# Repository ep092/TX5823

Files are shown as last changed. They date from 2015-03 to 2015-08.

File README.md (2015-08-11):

# TX5823
FPV Sender mit Kanalwahl und konfiguration über SPI. Integriertes OSD mit MAX7456 und Spannungswandlern für 5V, 3,3V und Vorbereitung für 12V, über einen Eingangsspannungsbereich von 8V bis 25.2V.
Das OSD ist kompatibel zu minimosd und wird mit dessen Firmware betrieben und mit der entsprechenden Software konfiguriert.
Die Kanalwahl folgt über einen freien Empfängerkanal.
Zusätzlich ist ein Infrarotauslöser für Canonkameras vorgesehen.

-------------------
Status:
- schaltplan fertig
- layout fertig
- platine bestellt
- Bauteile bestellt
- platine bestückt
- Tests erfolgreich

-------------------
Steckerbelegung 3-reihige Pinleiste(Orientierung Pinleiste nach links, oben 1):

untere Reihe, mittlere Reihe, obere Reihe

1. GND, NC, Video in
2. GND, NC, Sound in
3. GND, NC, PWM in
4. Infrator LED -, NC, Infrarot LED +
5. GND, 5V out, NC
6. GND. 5V out, NC
7. GND, 12V out (optional), NC
8. GND, 12V out (optional), NC

-------------------

Steckerbelegung mavlink Stecker

1. DTR (für Reset über USB)
2. TX (Atmega Daten Senden)
3. RX (Atmega Daten Empfangen)
4. 5/3,3V
5. GND

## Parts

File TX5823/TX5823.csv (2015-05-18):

Reference | Value | Footprint | Datasheet | Teilenummer | Bestellnummer | Anzahl lagernd
U2 | TPS54531 | toni:SO8_EP |  |  |  | 3 | d
U6 | TX5823 | toni:TX5823 |  |  |  | 0
U7 | MAX7456_DS | toni:TSSOP-28_4.4x9.7mm_Pitch0.65mm_EP |  |  |  | 4
IC1 | ATMEGA328P-A | Housings_QFP:TQFP-32_7x7mm_Pitch0.8mm |  |  |  | 20
IC2 | ATTINY13A-SS | SMD_Packages:SOIC-8-N |  |  |  | 20
R24 | 10k | Resistors_SMD:R_0603 |  |  |  | 0 | d
U3 | TPS7A7200RGT | toni:QFN-16-1EP_3x3mm_Pitch0.5mm |  |  |  | 3
R23 | 10 | Resistors_SMD:R_0805 |  |  |  | x
Q3 | MOSFET_N | toni:SOT23_GDS |  |  |  | x
R25 | 100 | Resistors_SMD:R_1206 |  |  |  | x
C29 | 100nF | Capacitors_SMD:C_0402 |  |  |  | x
C31 | 100nF | Capacitors_SMD:C_0402 |  |  |  | x
C19 | 1uF | Capacitors_SMD:C_0603 |  |  |  | x
C21 | 100nF | Capacitors_SMD:C_0402 |  |  |  | x
C32 | 1uF | Capacitors_SMD:C_0603 |  |  |  | x
C26 | 1uF | Capacitors_SMD:C_0603 |  |  |  | x
C27 | 10uF | Capacitors_SMD:C_1206 |  |  |  | x
C22 | 100nF | Capacitors_SMD:C_0402 |  |  |  | x
R17 | open | Resistors_SMD:R_0402 |  |  |  | x
R19 | open | Resistors_SMD:R_0402 |  |  |  | x
R20 | open | Resistors_SMD:R_0402 |  |  |  | x
C23 | 100nF | Capacitors_SMD:C_0402 |  |  |  | x
SW1 | SW_PUSH | toni:EVQP7A |  |  |  | 0 | d
R13 | 10k | Resistors_SMD:R_0603 |  |  |  | 0 | d
C20 | 100nF | Capacitors_SMD:C_0402 |  |  |  | x
Y1 | 16MHz | toni:CerOsc_3,2x1,3 |  |  |  | 0 | r
R21 | open | Resistors_SMD:R_0402 |  |  |  | x
R22 | 330 | Resistors_SMD:R_0805 |  |  |  | 0 | d
D6 | LED | LEDs:LED-0603 |  |  |  | x
C35 | 47uF | Capacitors_Tantalum_SMD:TantalC_SizeB_EIA-3528_Reflow |  |  |  | 0 | d
C36 | 47uF | Capacitors_Tantalum_SMD:TantalC_SizeB_EIA-3528_Reflow |  |  |  | 0 | d
R29 | 75 | Capacitors_SMD:C_0805 |  |  |  | 0 | d
C33 | 100nF | Capacitors_SMD:C_0402 |  |  |  | x
C34 | 1uF | Capacitors_SMD:C_0603 |  |  |  | x
C37 | 100nF/NP0 | Capacitors_SMD:C_1206 |  | C3216C0G1H104J160AA |  | 0
R30 | 75 | Capacitors_SMD:C_0805 |  |  |  | r
C30 | 100nF | Capacitors_SMD:C_0402 |  |  |  | x
RP1 | 1k | Resistors_SMD:R_Array_Concave_4x0603 |  |  |  | 0 | r
P2 | ISP | toni:micro_match3x2 |  |  |  | 0 | r
X1 | 27MHz | toni:CRYSTAL_MT |  |  | NDK NX3225SA-27.000MHZ-STD-CSR-1 | 0 | d
C24 | 100nF | Capacitors_SMD:C_0402 |  |  |  | x
C25 | 100nF | Capacitors_SMD:C_0402 |  |  |  | x
C28 | 1uF | Capacitors_SMD:C_0603 |  |  |  | x
C14 | Cboot | Capacitors_SMD:C_0402 |  | C1005X5R1A104K |  | 0 | d
D1 | DIODE | toni:POWERDI5 |  | PDS760-13 |  | 0 | d
L1 | INDUCTOR | Choke_SMD:Choke_SMD_Wuerth-WE-PD-Typ-LS_Handsoldering |  |  |  | 4 | d
R10 | Rfbt | Resistors_SMD:R_0402 |  | CRCW040210K2FKED |  | 0 | d
R11 | Rfbb | Resistors_SMD:R_0402 |  | CRCW04021K96FKED |  | 0 | d
C16 | Cout | Capacitors_SMD:C_1210 |  | GRM32ER61E226KE15L |  | 0 | d
C11 | 10nF | Capacitors_SMD:C_0402 |  | GRM033R61A822KA01D |  | 0 | evtl
C8 | Ccomp | Capacitors_SMD:C_0805 |  | CC0805JRNPO9BN102 |  | 0 | d
R6 | Rcomp | Resistors_SMD:R_0402 |  | CRCW040252K3FKED |  | 0 | d
C5 | Ccomp2 | Capacitors_SMD:C_0805 |  | C0805C180K5GACTU |  | 0 | d
C3 | Cin | Capacitors_SMD:C_1210 |  | GRM32ER71H475KA88L |  | 0 | d
C17 | Cout | Capacitors_SMD:C_1210 |  | GRM32ER61E226KE15L |  | 0 | d
C1 | Cin | Capacitors_SMD:C_1210 |  | GRM32ER71H475KA88L |  | 0 | d
U4 | CONN_03X08 | toni:Conn_03x08 |  |  |  | 4
R12 | open | Resistors_SMD:R_0603 |  |  |  | x
R14 | open | Resistors_SMD:R_0603 |  |  |  | x
R15 | 0R | Resistors_SMD:R_0603 |  |  |  | x
R16 | open | Resistors_SMD:R_0603 |  |  |  | x
P3 | Mavlink | Connectors_Molex:Connector_Molex_PicoBlade_53261-0571 |  |  |  | 4
R27 | 1k | Resistors_SMD:R_0603 |  |  |  | r
R18 | 330R | Resistors_SMD:R_0805 |  |  |  | r
R28 | 1k | Resistors_SMD:R_0603 |  |  |  | r
P1 | Akku_in | Socket_Strips:Socket_Strip_Angled_1x02 |  |  |  | x
R31 | 330R | Capacitors_SMD:C_0805 |  |  |  | r
SMA_E1 | SMA_EDGE | toni:SMA_EDGE |  |  |  | 0 | phil
C2 | 220pF | Capacitors_SMD:C_0402 |  |  |  | 0 | d
U1 | TPS7A7200RGT | toni:QFN-16-1EP_3x3mm_Pitch0.5mm |  |  |  | r
C4 | 1uF | Capacitors_SMD:C_0603 |  |  |  | x
C6 | 100nF | Capacitors_SMD:C_0402 |  |  |  | x
C12 | 1uF | Capacitors_SMD:C_0603 |  |  |  | x
C7 | 100nF | Capacitors_SMD:C_0402 |  |  |  | x
C10 | 220pF | Capacitors_SMD:C_0402 |  |  |  | r
C13 | 10uF | Capacitors_SMD:C_1206 |  |  |  | x
Q1 | MOSFET_P | toni:SO8_WITH_EP |  | FDS4141 |  | x
R2 | R | Resistors_SMD:R_0603 |  |  |  | x
R1 | R | Resistors_SMD:R_0603 |  |  |  | x
R3 | R | Resistors_SMD:R_1206 |  | ersetzen durch ferrit s.u. |  | x
C9 | C | Capacitors_SMD:C_0603 |  |  |  | x
D2 | ZENER | Diodes_SMD:Diode-MiniMELF_Standard |  |  |  | x
R4 | 280k | Resistors_SMD:R_0603 |  | 0,10% |  | 0 | d
R5 | 30,9k | Resistors_SMD:R_0603 |  | 0,10% |  | 0 | d
P4 | CONN_01X01 | Pin_Headers:Pin_Header_Straight_1x01 |  |  |  | x
P5 | CONN_01X01 | Pin_Headers:Pin_Header_Straight_1x01 |  |  |  | x
P6 | CONN_01X01 | Pin_Headers:Pin_Header_Straight_1x01 |  |  |  | x
P7 | CONN_01X01 | Pin_Headers:Pin_Header_Straight_1x01 |  |  |  | x
U9 | TPS22963 | toni:DSBGS(6) |  |  |  | x
U5 | OPTO-TRANSISTOR4 | toni:SO-4 |  |  |  | 16
U8 | ADuM7241 ARZ | Housings_SOIC:SOIC-8_3.9x4.9mm_Pitch1.27mm |  |  |  | 3 | d
U10 | OPTO-TRANSISTOR4 | toni:SO-4 |  |  |  | r
R8 | 330R | Resistors_SMD:R_0603 |  |  |  | r
R7 | 10k | Resistors_SMD:R_0603 |  |  |  | 0 | d
C15 | 100nF | Capacitors_SMD:C_0402 |  |  |  | x
C18 | 100nF | Capacitors_SMD:C_0402 |  |  |  | x
D3 | P6SMB 27A SMD | Diodes_SMD:Diode-SMB_Standard |  |  |  | 0 | r
 | ferrit würth |  |  | 742792150 |  | 0 | d

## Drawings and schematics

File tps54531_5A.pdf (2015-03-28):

## WEBENCH ® Design Report

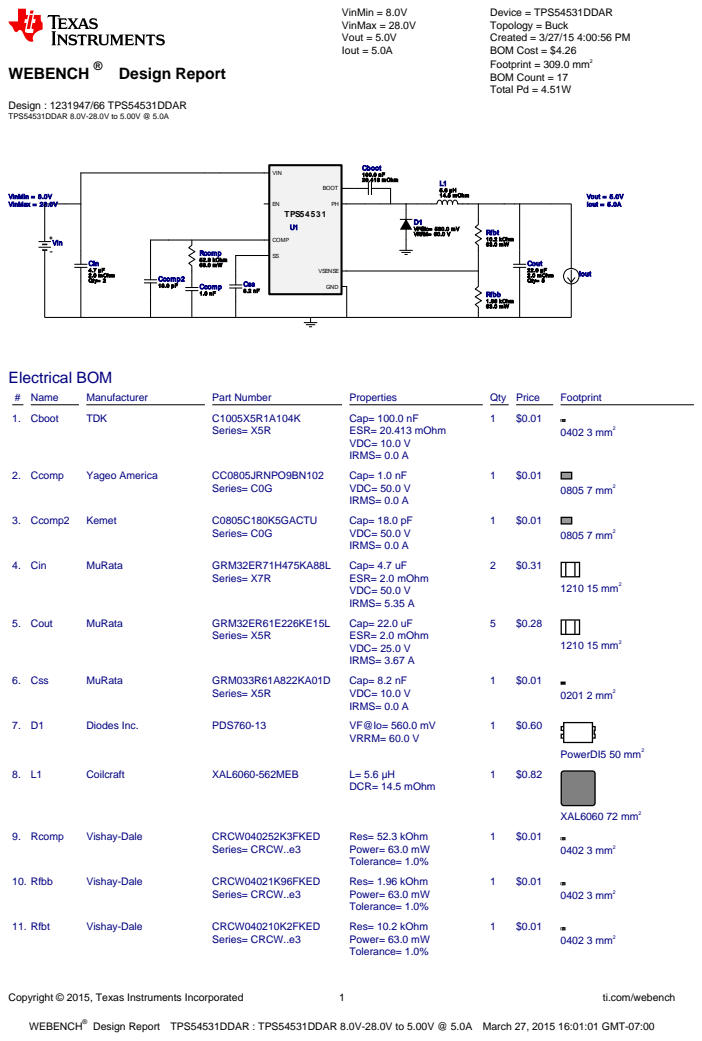
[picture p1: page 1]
Copyright © 2015, Texas Instruments Incorporated; ti.com/webench; WEBENCH®; Design : 1231947/66 TPS54531DDAR TPS54531DDAR 8.0V-28.0V to 5.00V @ 5.0A; VinMin = 8.0V VinMax = 28.0V Vout = 5.0V Iout = 5.0A; Device = TPS54531DDAR Topology = Buck Created = 3/27/15 4:00:56 PM BOM Cost = $4.26 Footprint = 309.0 mm² BOM Count = 17 Total Pd = 4.51W; Cboot 100.0 nF 20.413 mOhm; Ccomp 1.0 nF; Ccomp2 18.0 pF; Cin 4.7 µF 2.0 mOhm Qty= 2; Cout 22.0 µF 2.0 mOhm Qty= 5 Css; D1 VF@Io= 560.0 mV VRRM= 60.0 V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

Design Report TPS54531DDAR : TPS54531DDAR 8.0V-28.0V to 5.00V @ 5.0A March 27, 2015 16:01:01 GMT-07:00

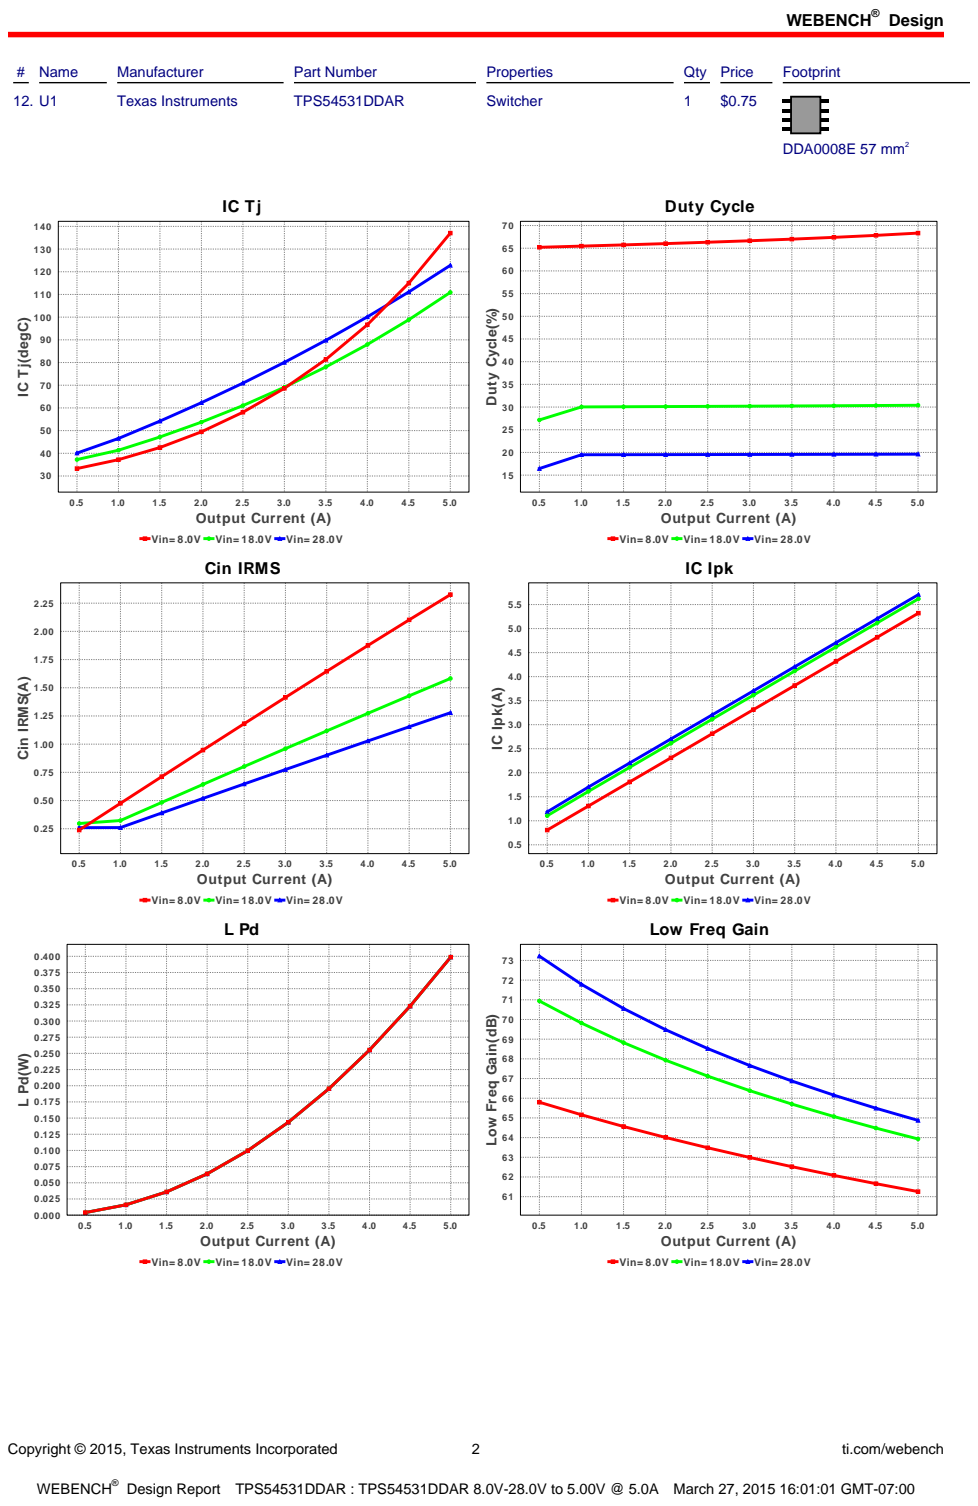
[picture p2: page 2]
Design; Copyright © 2015, Texas Instruments Incorporated; ti.com/webench; # Name; Manufacturer; Part Number; Properties; Qty Price; Footprint; Texas Instruments; TPS54531DDAR; Switcher; DDA0008E 57 mm²; 5.0 Output Current (A); Duty Cycle; Duty Cycle(%); Cin IRMS(A); IC Ipk; IC Ipk(A)

IC Tj(degC)

Vin= 8.0V Vin= 18.0V Vin= 28.0V
Cin IRMS

Low Freq Gain

Low Freq Gain(dB)

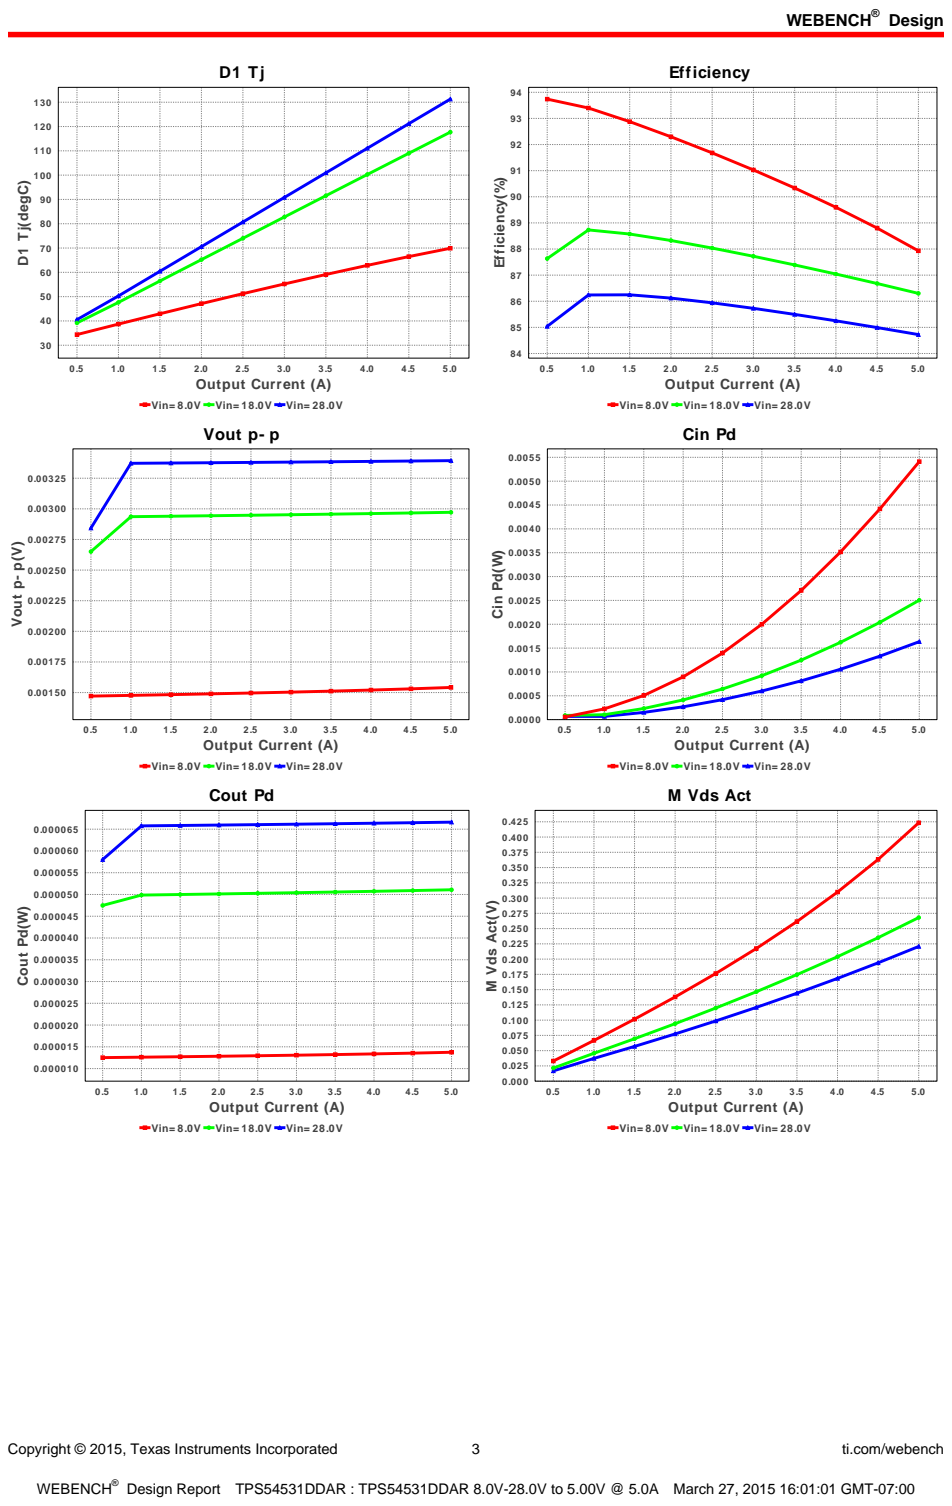
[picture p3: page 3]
Copyright © 2015, Texas Instruments Incorporated; ti.com/webench; 5.0 Output Current (A); D1 Tj(degC); Efficiency; Efficiency(%); Vout p- p(V); Cin Pd; Cin Pd(W); Cout Pd(W); M Vds Act(V)

Vin= 8.0V Vin= 18.0V Vin= 28.0V
Vout p- p

Cout Pd

M Vds Act

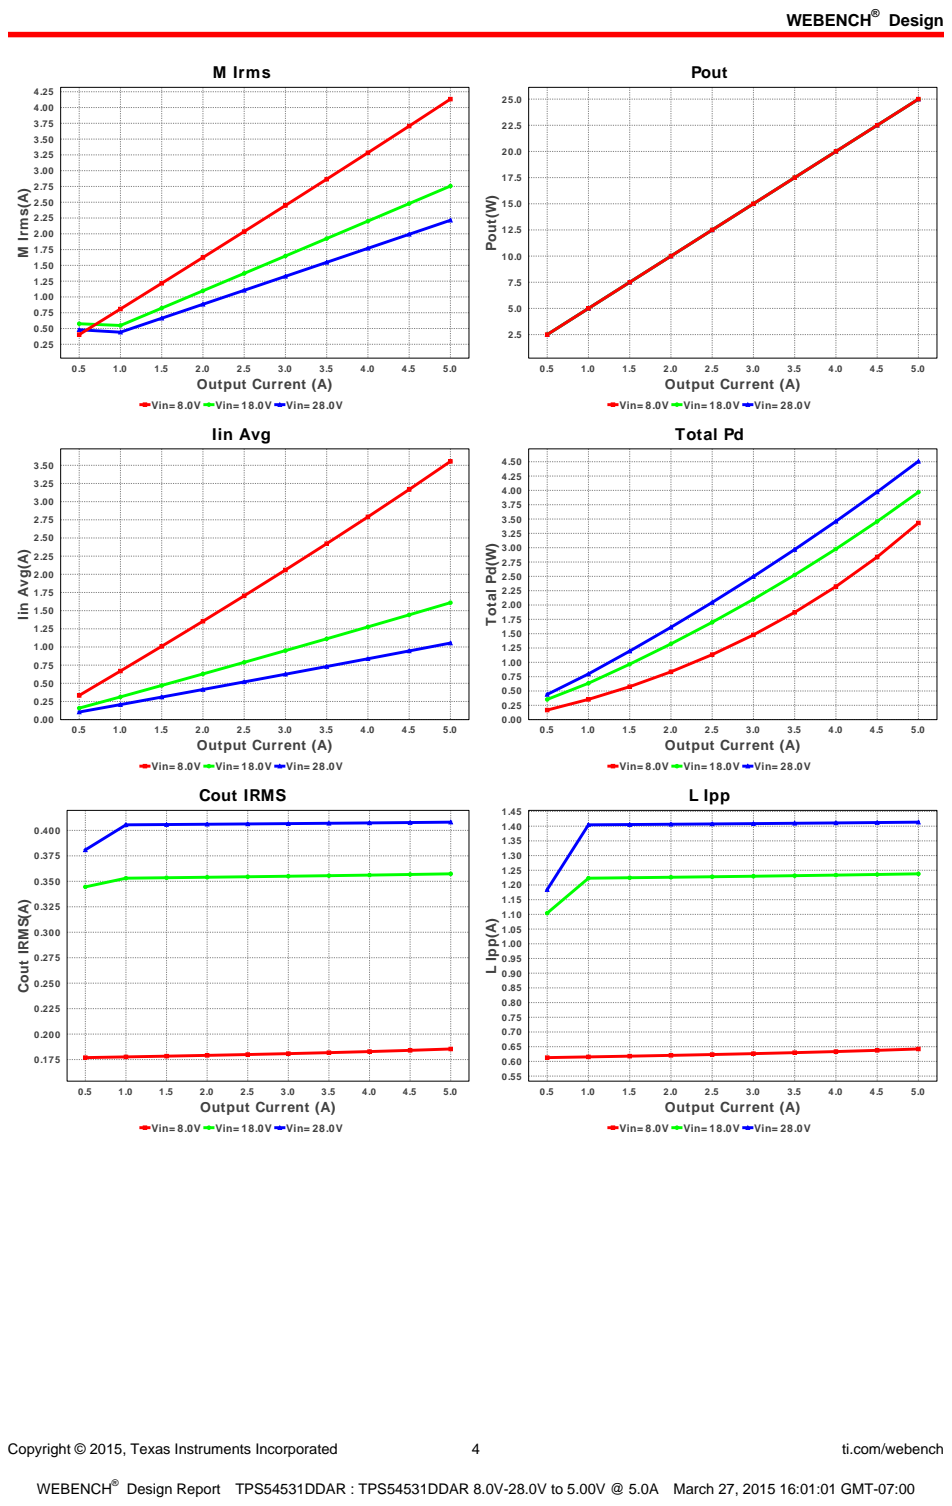
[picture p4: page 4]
Copyright © 2015, Texas Instruments Incorporated; ti.com/webench; M Irms; 5.0 Output Current (A); M Irms(A); Pout; Pout(W); Iin Avg; Iin Avg(A); Total Pd(W); Cout IRMS(A); L Ipp; L Ipp(A)

Vin= 8.0V Vin= 18.0V Vin= 28.0V

Total Pd

Cout IRMS

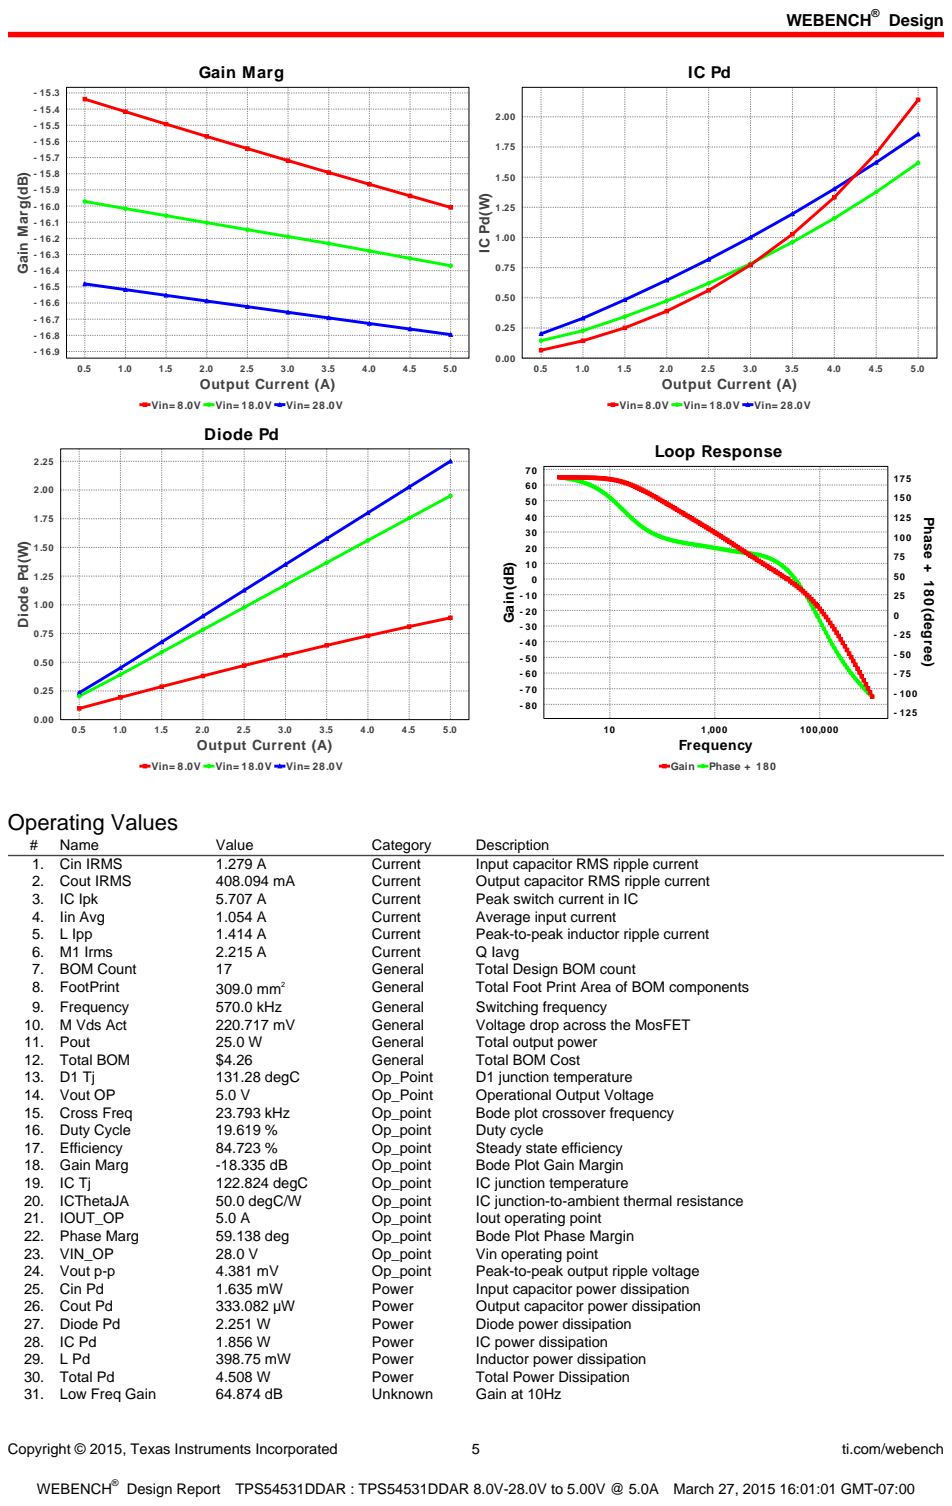
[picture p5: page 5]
Copyright © 2015, Texas Instruments Incorporated; ti.com/webench; Gain Marg; 5.0 Output Current (A); Diode Pd(W); Loop Response; Gain Phase + 180; 100,000 Frequency; Gain(dB); Phase + 180(degree); Operating Values; Name; Value; Category; Description; 1. Cin IRMS; Current; Input capacitor RMS ripple current; 2. Cout IRMS; Output capacitor RMS ripple current; 3. IC Ipk; Peak switch current in IC; 4. Iin Avg; Average input current; 5. L Ipp; Peak-to-peak inductor ripple current; 6. M1 Irms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

Gain Marg(dB)

Vin= 8.0V Vin= 18.0V Vin= 28.0V
Diode Pd

Copyright © 2015, Texas Instruments Incorporated | 6 | ti.com/webench

## Design Inputs

# | Name | Value | Description

1. Iout | 5.0 | Maximum Output Current
2. Iout1 | 5.0 | Output Current #1
3. VinMax | 28.0 | Maximum input voltage
4. VinMin | 8.0 | Minimum input voltage
5. Vout | 5.0 | Output Voltage
6. Vout1 | 5.0 | Output Voltage #1
7. base_pn | TPS54531 | Base Product Number
8. source | DC | Input Source Type
9. Ta | 30.0 | Ambient temperature

## Design Assistance

1. TPS54531 Product Folder : http://www.ti.com/product/tps54531 : contains the data sheet and other resources.

Texas Instruments' WEBENCH simulation tools attempt to recreate the performance of a substantially equivalent physical implementation
of the design. Simulations are created using Texas Instruments' published specifications as well as the published specifications of other device manufacturers. While Texas Instruments does update this information periodically, this information may not be current at the time the simulation is built. Texas Instruments does not warrant the accuracy or completeness of the specifications or any information contained therein. Texas Instruments does not warrant that any designs or recommended parts will meet the specifications you entered, will be suitable for your application or fit for any particular purpose, or will operate as shown in the simulation in a physical implementation. Texas Instruments does not warrant that the designs are production worthy.
You should completely validate and test your design implementation to confirm the system functionality for your application prior to production.
Use of Texas Instruments' WEBENCH simulation tools is subject to Texas Instruments' Site Terms and Conditions of Use. (http://www.ti.com/corp/docs/legal/termsofuse.shtml) Prototype boards based on WEBENCH created designs are provided AS IS without warranty of any kind for evaluation and testing purposes and are subject to the terms of the Evaluation License Agreement. (http://www.ti.com/corp/docs/legal/termsofuse_estore.shtml)

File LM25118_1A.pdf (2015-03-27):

## WEBENCH ® Design Report

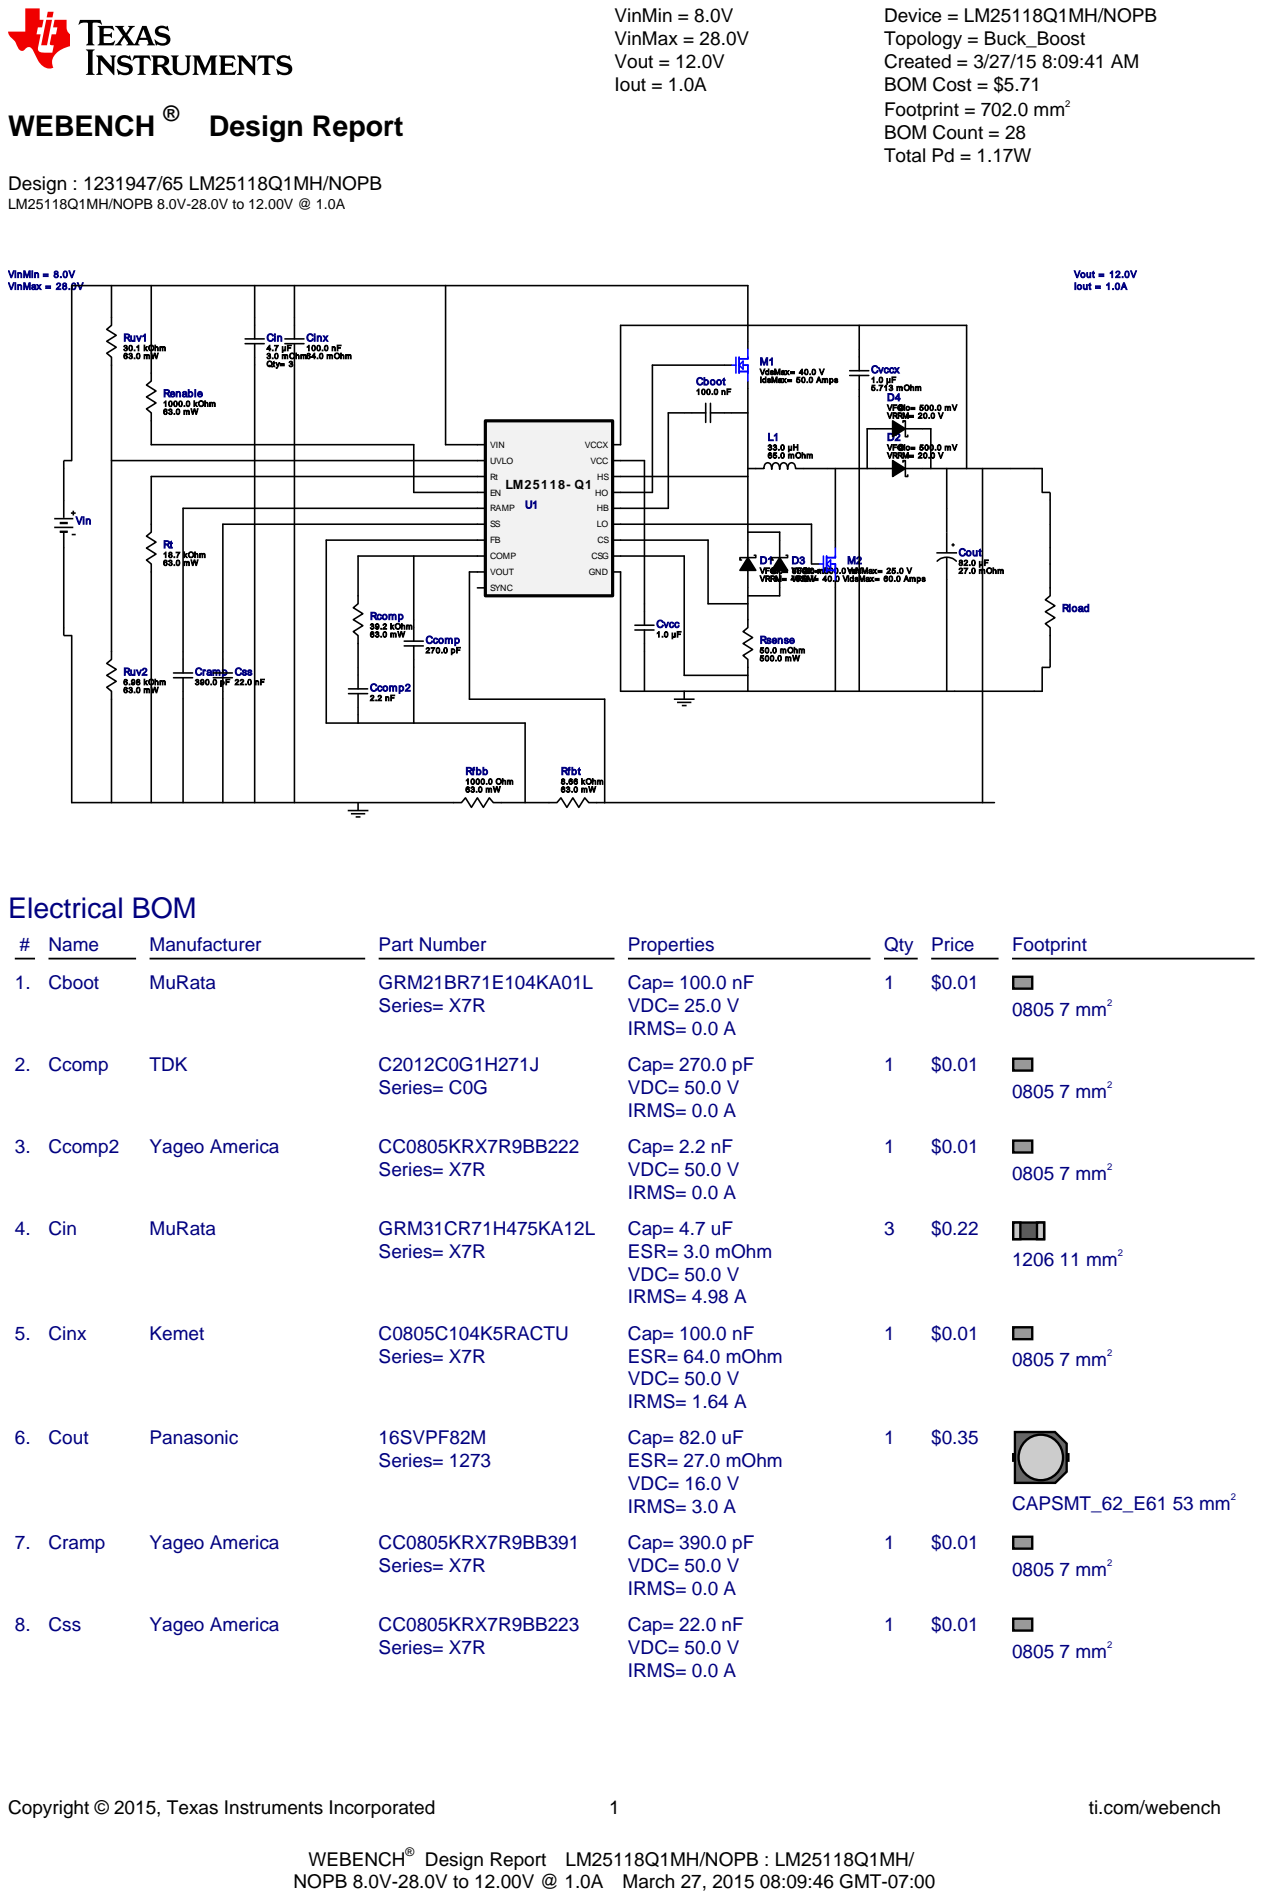
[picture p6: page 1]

WEBENCH®
NOPB 8.0V-28.0V to 12.00V @ 1.0A March 27, 2015 08:09:46 GMT-07:00

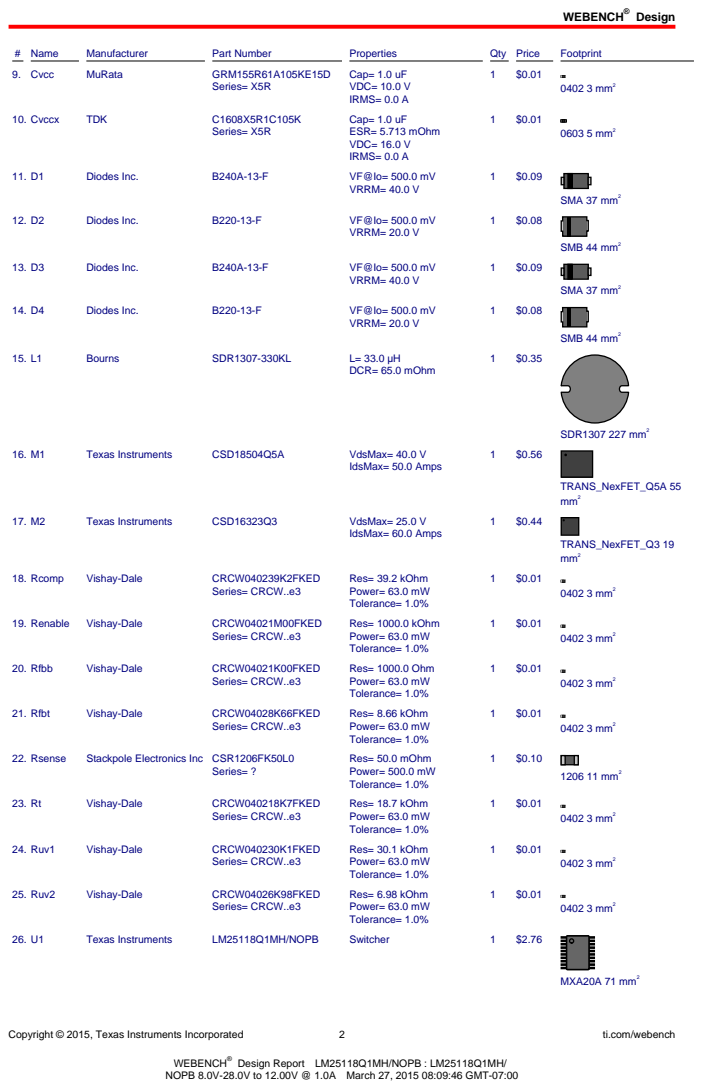
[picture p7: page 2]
Design; Copyright © 2015, Texas Instruments Incorporated; ti.com/webench; # Name; Manufacturer; Part Number; Properties; Qty Price; Footprint; 9. Cvcc; MuRata; GRM155R61A105KE15D; Series= X5R; Cap= 1.0 uF VDC= 10.0 V IRMS= 0.0 A; 0402 3 mm²; 10. Cvccx; TDK; Cap= 1.0 uF ESR= 5.713 mOhm VDC= 16.0 V IRMS= 0.0 A; 0603 5 mm²; Diodes Inc.; VRRM= 40.0 V; SMA 37 mm²; VRRM= 20.0 V; SMB 44 mm²; Bourns; SDR1307-330KL; DCR= 65.0 mOhm; SDR1307 227 mm²; Texas Instruments; CSD18504Q5A; VdsMax= 40.0 V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

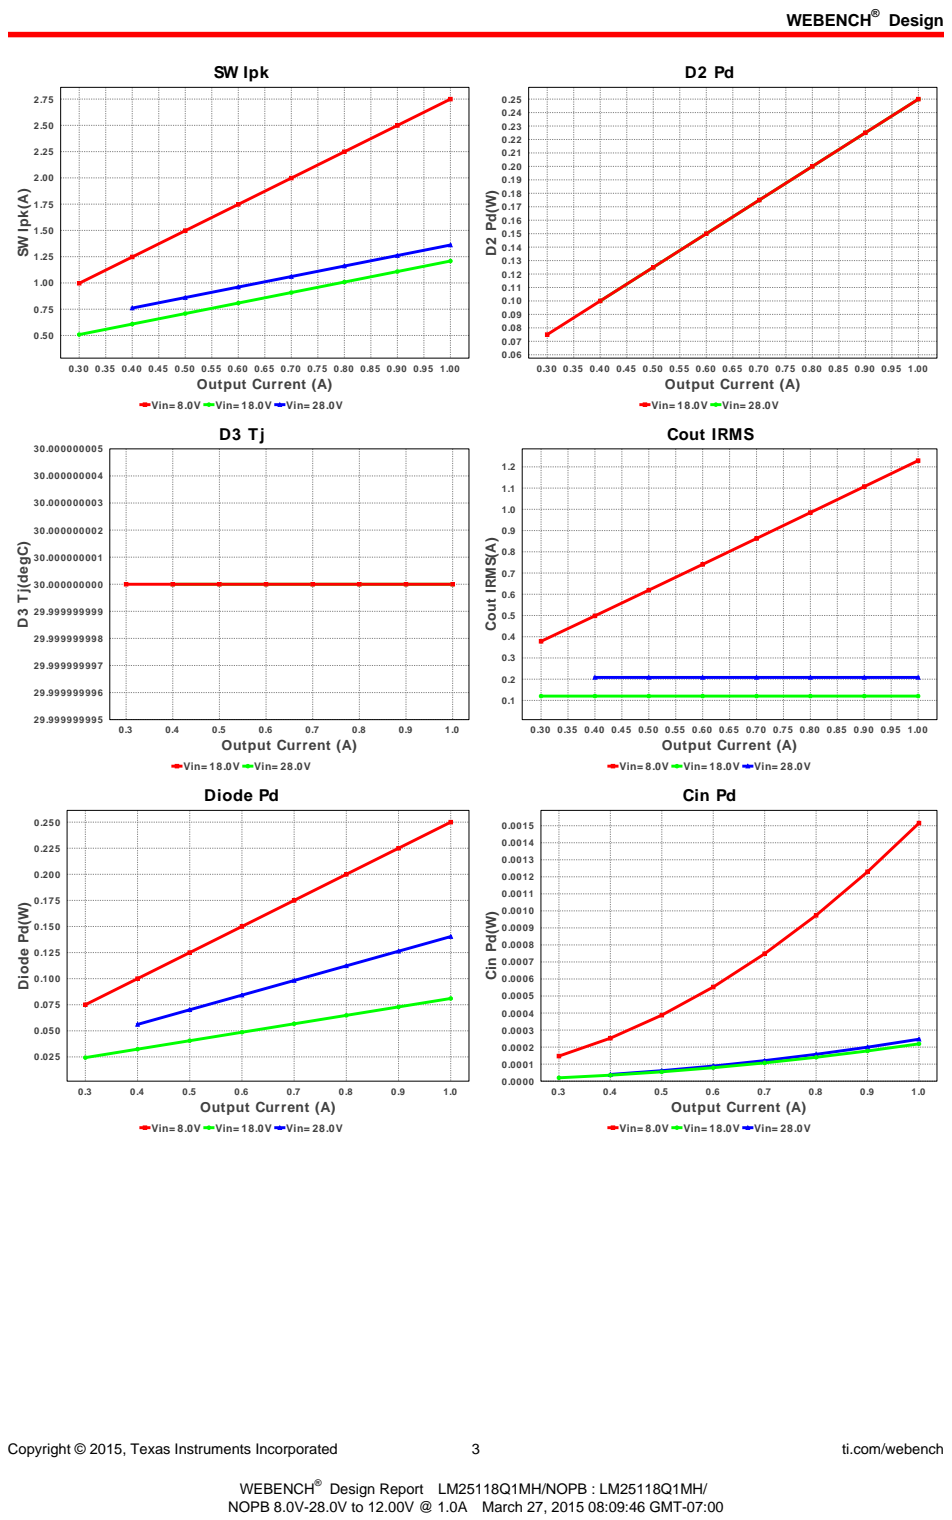
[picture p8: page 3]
Copyright © 2015, Texas Instruments Incorporated; ti.com/webench; SW Ipk; 0.30 0.35 0.40 0.45 0.50 0.55 0.60 0.65 0.70 0.75 0.80 0.85 0.90 0.95 1.00 Output Current (A); SW Ipk(A); Vin= 18.0V Vin= 28.0V; 1.0 Output Current (A); D3 Tj(degC); Cout IRMS; Cout IRMS(A); Diode Pd; Diode Pd(W); Cin Pd; Cin Pd(W)

Vin= 8.0V Vin= 18.0V Vin= 28.0V

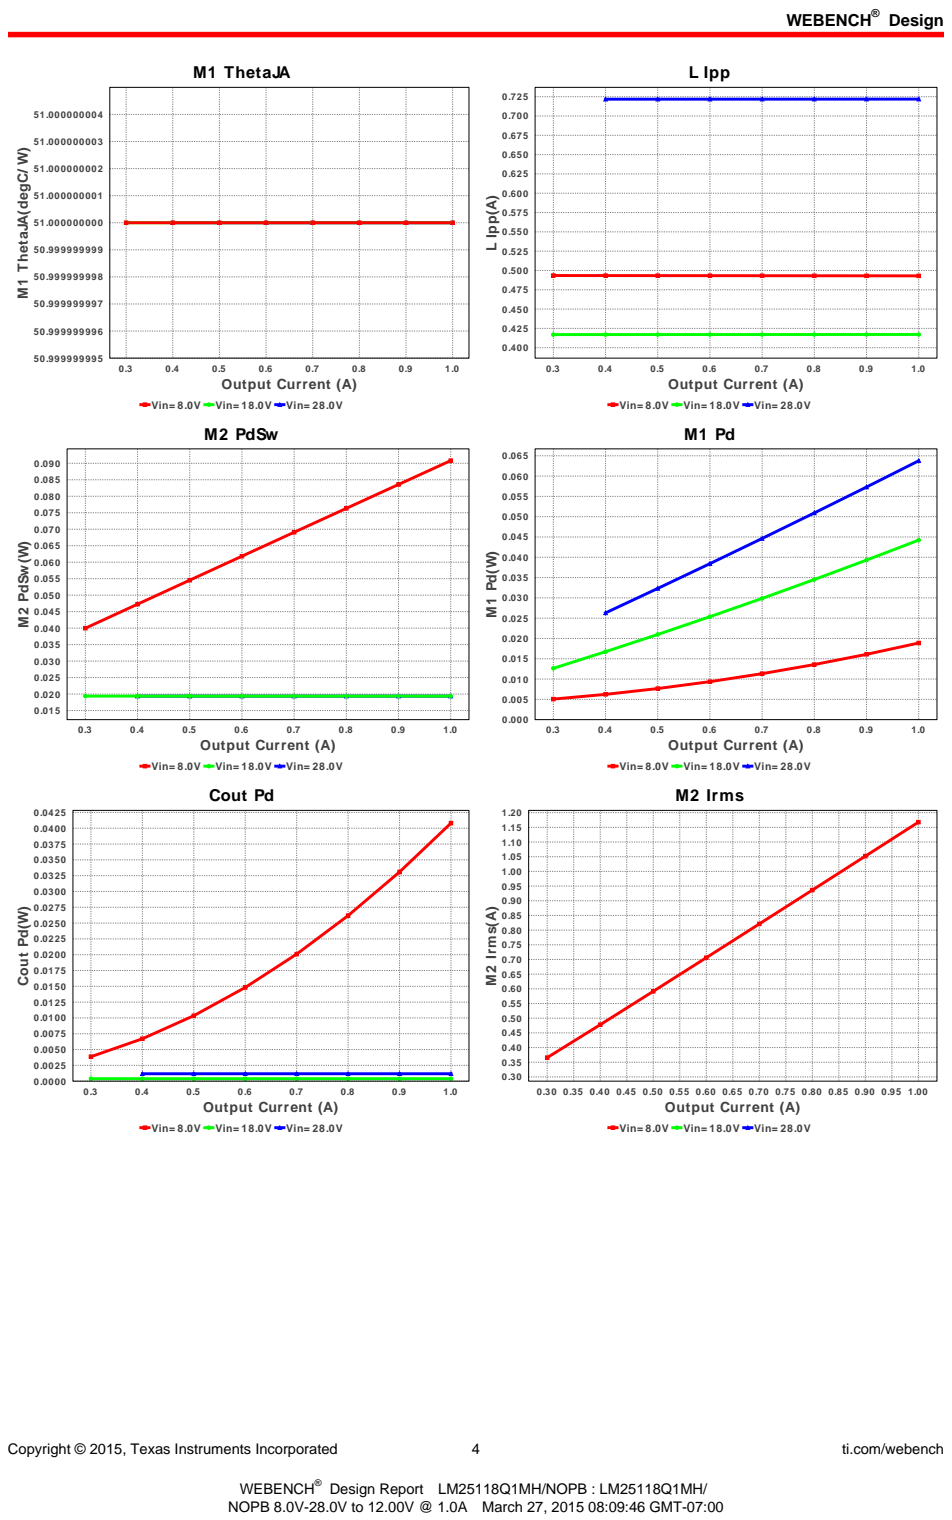
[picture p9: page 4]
Copyright © 2015, Texas Instruments Incorporated; ti.com/webench; M1 ThetaJA; 1.0 Output Current (A); M1 ThetaJA(degC/ W); L Ipp; L Ipp(A); M2 PdSw(W); Cout Pd(W); 0.30 0.35 0.40 0.45 0.50 0.55 0.60 0.65 0.70 0.75 0.80 0.85 0.90 0.95 1.00 Output Current (A); M2 Irms(A)

Vin= 8.0V Vin= 18.0V Vin= 28.0V
M2 PdSw

Cout Pd

M2 Irms

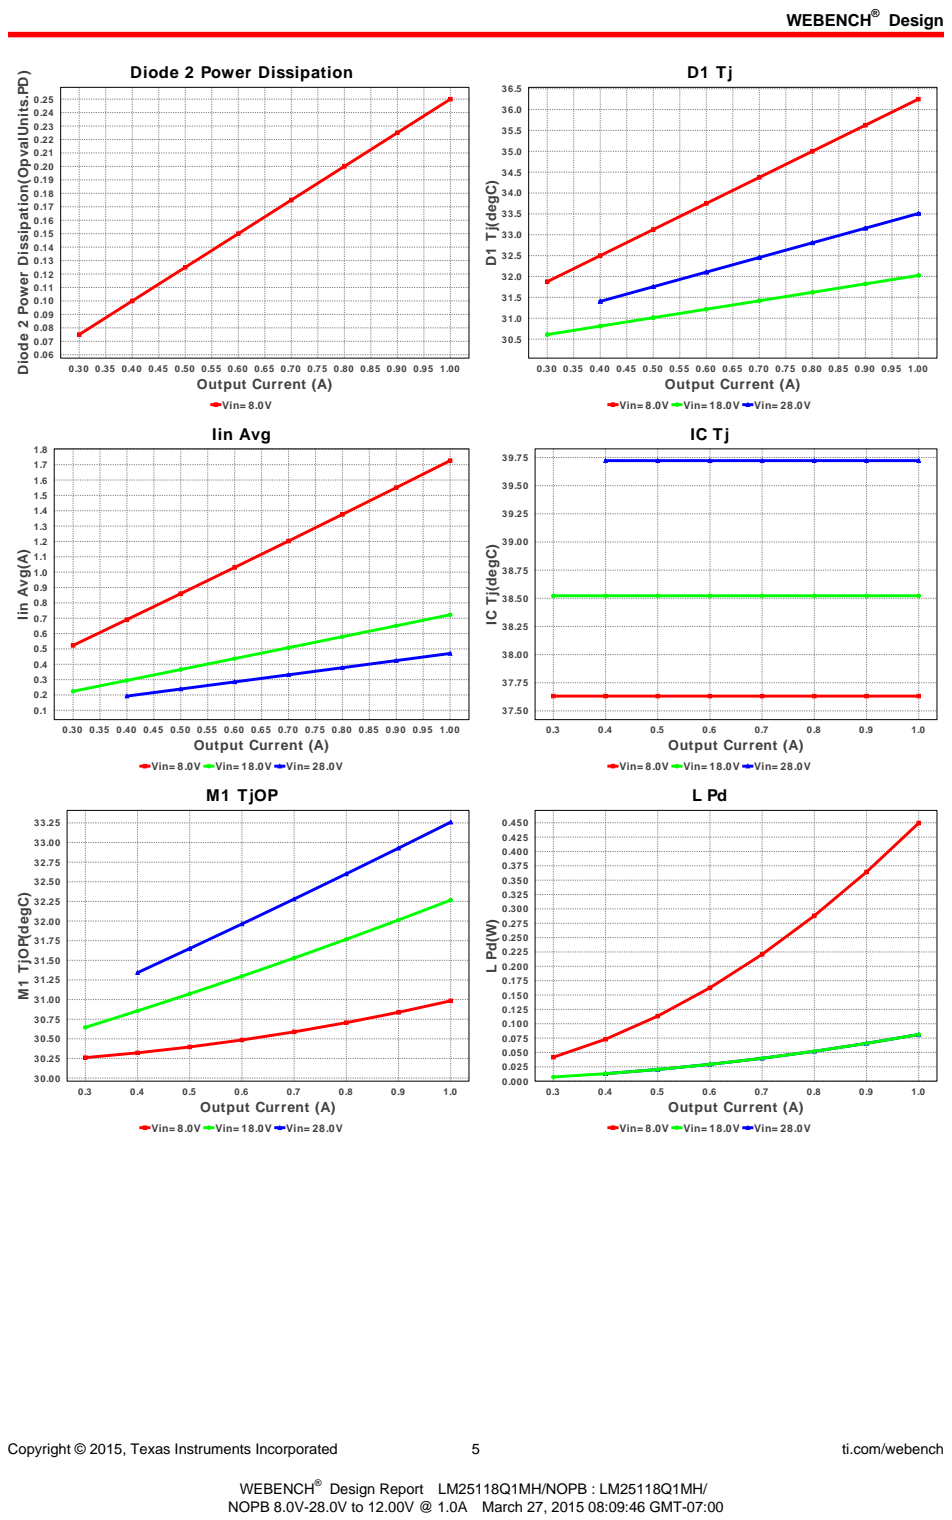
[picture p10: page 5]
Copyright © 2015, Texas Instruments Incorporated; ti.com/webench; Vin= 8.0V; 0.30 0.35 0.40 0.45 0.50 0.55 0.60 0.65 0.70 0.75 0.80 0.85 0.90 0.95 1.00 Output Current (A); D1 Tj(degC); Iin Avg; Iin Avg(A); 1.0 Output Current (A); M1 TjOP(degC)

Diode 2 Power Dissipation(OpvalUnits.PD)

Diode 2 Power Dissipation

Vin= 8.0V Vin= 18.0V Vin= 28.0V

IC Tj(degC)

M1 TjOP

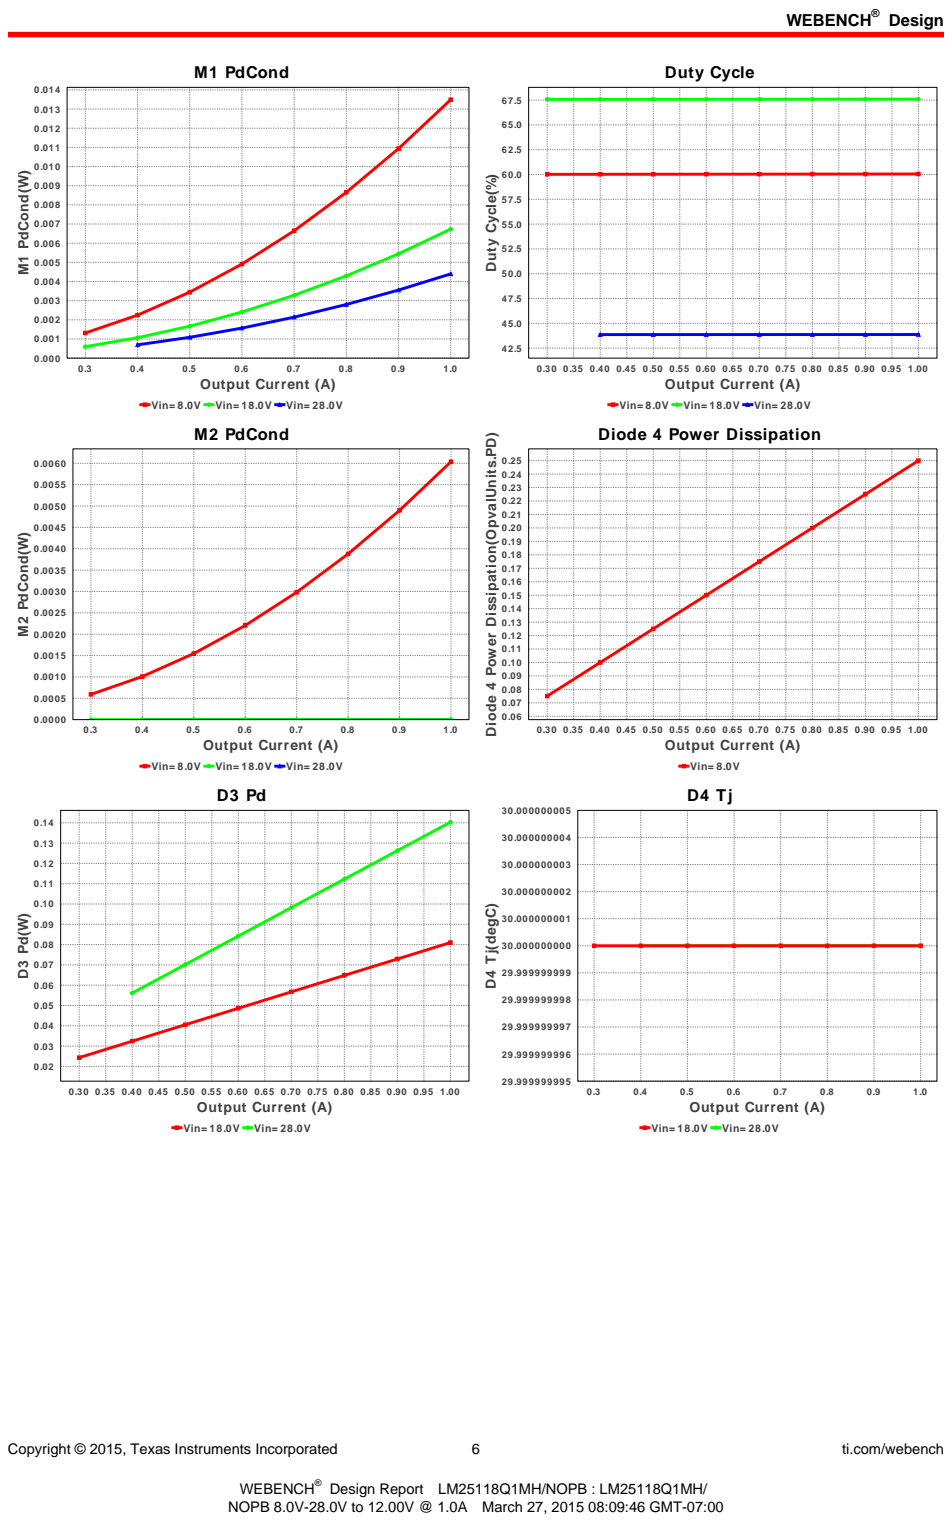
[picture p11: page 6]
Copyright © 2015, Texas Instruments Incorporated; ti.com/webench; M1 PdCond; 1.0 Output Current (A); M1 PdCond(W); Duty Cycle; 0.30 0.35 0.40 0.45 0.50 0.55 0.60 0.65 0.70 0.75 0.80 0.85 0.90 0.95 1.00 Output Current (A); Duty Cycle(%); M2 PdCond(W); Vin= 8.0V; Vin= 18.0V Vin= 28.0V; D4 Tj(degC)

Vin= 8.0V Vin= 18.0V Vin= 28.0V
M2 PdCond

Diode 4 Power Dissipation

Diode 4 Power Dissipation(OpvalUnits.PD)

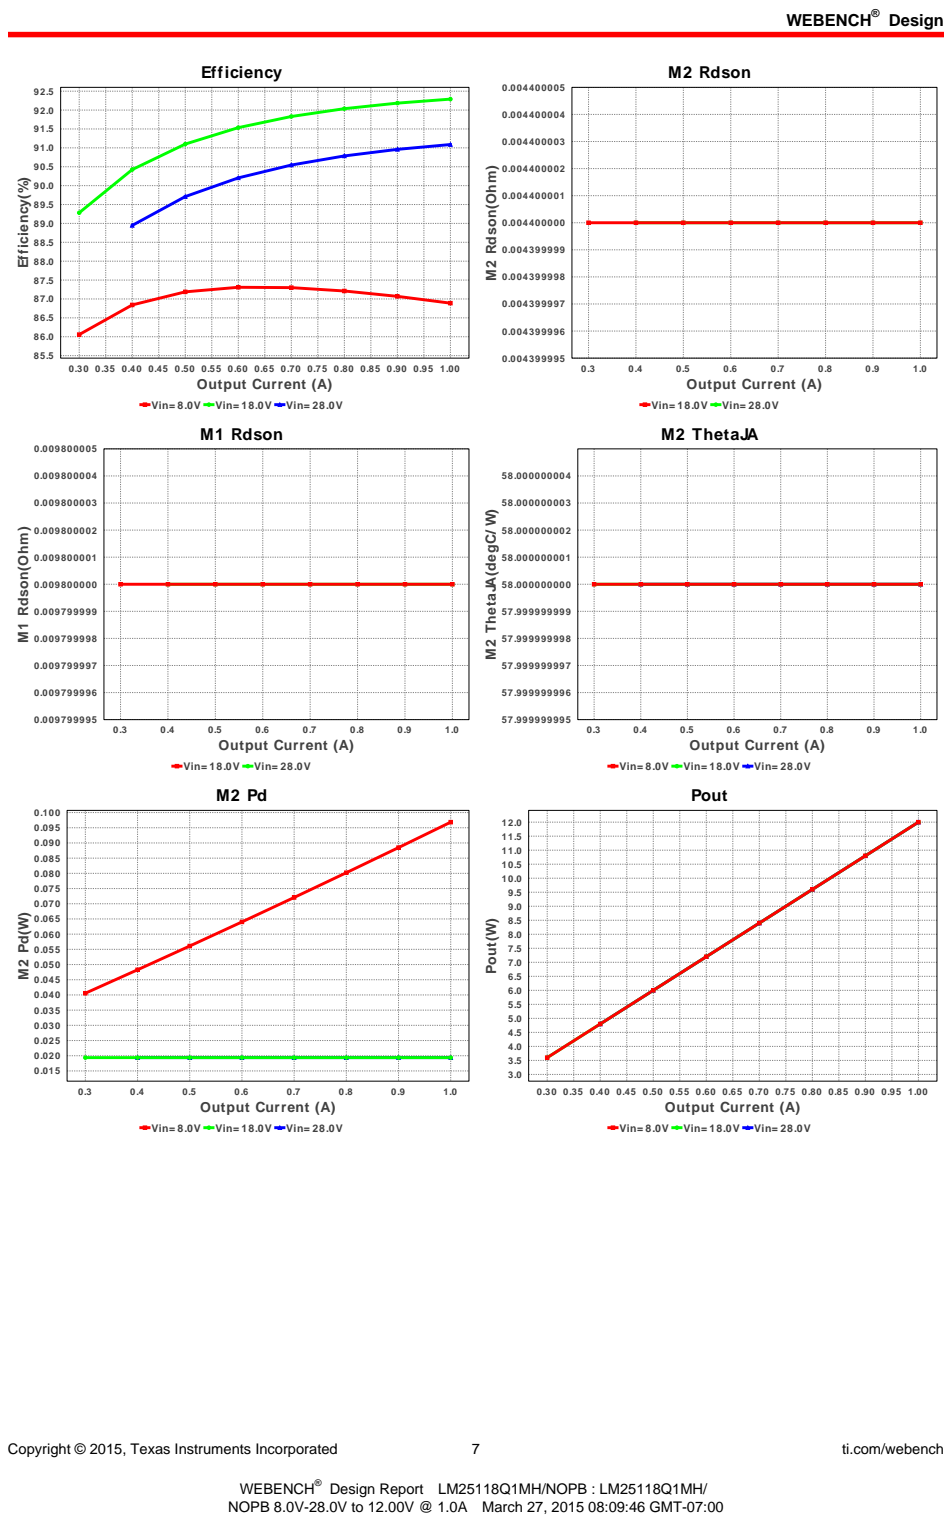
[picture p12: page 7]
Copyright © 2015, Texas Instruments Incorporated; ti.com/webench; Efficiency; 0.30 0.35 0.40 0.45 0.50 0.55 0.60 0.65 0.70 0.75 0.80 0.85 0.90 0.95 1.00 Output Current (A); Efficiency(%); M2 Rdson; Vin= 18.0V Vin= 28.0V; 1.0 Output Current (A); M2 Rdson(Ohm); M1 Rdson(Ohm); M2 ThetaJA; M2 ThetaJA(degC/ W); Pout; Pout(W)

Vin= 8.0V Vin= 18.0V Vin= 28.0V
M1 Rdson

Copyright © 2015, Texas Instruments Incorporated; ti.com/webench; M1 PdSw; 1.0 Output Current (A); M1 PdSw(W); Total Pd; Total Pd(W); Vin= 18.0V Vin= 28.0V; 0.30 0.35 0.40 0.45 0.50 0.55 0.60 0.65 0.70 0.75 0.80 0.85 0.90 0.95 1.00 Output Current (A); D2 Tj(degC); M1 Irms(A)

Vin= 8.0V Vin= 18.0V Vin= 28.0V

M1 Irms

Copyright © 2015, Texas Instruments Incorporated; ti.com/webench; Vin= 8.0V; 0.30 0.35 0.40 0.45 0.50 0.55 0.60 0.65 0.70 0.75 0.80 0.85 0.90 0.95 1.00 Output Current (A); L1 Irms; L1 Irms(A); M2 TjOP; 1.0 Output Current (A); M2 TjOP(degC); Vin= 18.0V Vin= 28.0V; Vout p- p; Vout p- p(V)

Diode 1 Power Dissipation(OpvalUnits.PD)

Diode 1 Power Dissipation

Vin= 8.0V Vin= 18.0V Vin= 28.0V
Diode 3 Power Dissipation

Diode 3 Power Dissipation(OpvalUnits.PD)

Copyright © 2015, Texas Instruments Incorporated; ti.com/webench; Cin IRMS; 0.30 0.35 0.40 0.45 0.50 0.55 0.60 0.65 0.70 0.75 0.80 0.85 0.90 0.95 1.00 Output Current (A); Cin IRMS(A); Loop Response; Gain Phase + 180; 100,000 Frequency; Gain(dB); Phase + 180(degree); Operating Values; Name; Value; Category; Description; 1. Cin IRMS; Current; Input capacitor RMS ripple current; 2. Cout IRMS; Output capacitor RMS ripple current; 3. Iin Avg; Average input current; 4. L Ipp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

Vin= 8.0V Vin= 18.0V Vin= 28.0V

Copyright © 2015, Texas Instruments Incorporated | 11 | ti.com/webench

## Design Inputs

# | Name | Value | Description

1. Iout | 1.0 | Maximum Output Current
2. Iout1 | 1.0 | Output Current #1
3. VinMax | 28.0 | Maximum input voltage
4. VinMin | 8.0 | Minimum input voltage
5. Vout | 12.0 | Output Voltage
6. Vout1 | 12.0 | Output Voltage #1
7. base_pn | LM25118-Q1 | Base Product Number
8. source | DC | Input Source Type
9. Ta | 30.0 | Ambient temperature

## Design Assistance
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

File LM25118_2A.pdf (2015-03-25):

## WEBENCH ® Design Report


WEBENCH®
NOPB 8.0V-30.0V to 12.00V @ 2.0A March 25, 2015 08:06:38 GMT-07:00

Design

Copyright © 2015, Texas Instruments Incorporated | 2 | ti.com/webench
# Name | Manufacturer | Part Number | Properties | Qty Price | Footprint

9. Cvcc | MuRata | GRM155R61A105KE15D (http://search.murata.co.jp/Ceramy/PnsearchViewAction.do) Series= X5R | Cap= 1.0 uF VDC= 10.0 V IRMS= 0.0 A
1 | $0.01
| | | | | 0402 3 mm²
10. Cvccx | TDK | C1608X5R1C105K (http://www.tdk.co.jp/tefe02/e2442%5Fc.pdf) Series= X5R | Cap= 1.0 uF ESR= 5.713 mOhm VDC= 16.0 V IRMS= 0.0 A
1 | $0.01
| | | | | 0603 5 mm²
11. D1 | Comchip Technology | CDBC540-G (http://www.comchip.com.tw/cms/UserFiles/QW%2DBB012%20CDBC520%2DG%7E5100%2DG%20RevC809622.pdf) | VF@Io= 550.0 mV VRRM= 40.0 V
1 | $0.23

SMC 83 mm²
12. D2 | Comchip Technology | CDBC540-G (http://www.comchip.com.tw/cms/UserFiles/QW%2DBB012%20CDBC520%2DG%7E5100%2DG%20RevC809622.pdf) | VF@Io= 550.0 mV VRRM= 40.0 V
1 | $0.23

SMC 83 mm²
13. D3 | Comchip Technology | CDBC540-G (http://www.comchip.com.tw/cms/UserFiles/QW%2DBB012%20CDBC520%2DG%7E5100%2DG%20RevC809622.pdf) | VF@Io= 550.0 mV VRRM= 40.0 V
1 | $0.23

SMC 83 mm²
14. D4 | Comchip Technology | CDBC540-G (http://www.comchip.com.tw/cms/UserFiles/QW%2DBB012%20CDBC520%2DG%7E5100%2DG%20RevC809622.pdf) | VF@Io= 550.0 mV VRRM= 40.0 V
1 | $0.23

SMC 83 mm²
15. L1 | Coilcraft | MSS1210-153MEB (http://www.coilcraft.com/pdfs/mss1210.pdf) | L= 15.0 µH DCR= 19.0 mOhm
1 | $0.81

MSS1210 204 mm²
16. M1 | Texas Instruments | CSD18504Q5A (http://www.ti.com/lit/ds/symlink/csd18504q5a.pdf) | VdsMax= 40.0 V IdsMax= 50.0 Amps
1 | $0.56

TRANS_NexFET_Q5A 55
mm²
17. M2 | Texas Instruments | CSD16340Q3 (http://www.ti.com/lit/ds/symlink/csd16340q3.pdf) | VdsMax= 25.0 V IdsMax= 60.0 Amps
1 | $0.44

TRANS_NexFET_Q3 19
mm²
18. Rcomp | Vishay-Dale | CRCW040246K4FKED (http://www.vishay.com/docs/20035/dcrcwe3.pdf) Series= CRCW..e3 | Res= 46.4 kOhm Power= 63.0 mW Tolerance= 1.0%
1 | $0.01
0402 3 mm²
19. Renable | Vishay-Dale | CRCW04021M00FKED (http://www.vishay.com/docs/20035/dcrcwe3.pdf) Series= CRCW..e3 | Res= 1000.0 kOhm Power= 63.0 mW Tolerance= 1.0%
1 | $0.01
0402 3 mm²
20. Rfbb | Vishay-Dale | CRCW04021K00FKED (http://www.vishay.com/docs/20035/dcrcwe3.pdf) Series= CRCW..e3 | Res= 1000.0 Ohm Power= 63.0 mW Tolerance= 1.0%
1 | $0.01
0402 3 mm²
21. Rfbt | Vishay-Dale | CRCW04028K66FKED (http://www.vishay.com/docs/20035/dcrcwe3.pdf) Series= CRCW..e3 | Res= 8.66 kOhm Power= 63.0 mW Tolerance= 1.0%
1 | $0.01
0402 3 mm²
22. Rsense | Susumu Co Ltd | PRL1632-R020-F-T1 (http://www.susumu.co.jp/english/pdf/products-j01-07.pdf) Series= 237 | Res= 20.0 mOhm Power= 1.0 W Tolerance= 1.0%
1 | $0.19
1206 11 mm²
23. Rt | Vishay-Dale | CRCW040218K7FKED (http://www.vishay.com/docs/20035/dcrcwe3.pdf) Series= CRCW..e3 | Res= 18.7 kOhm Power= 63.0 mW Tolerance= 1.0%
1 | $0.01
0402 3 mm²
24. Ruv1 | Vishay-Dale | CRCW040232K4FKED (http://www.vishay.com/docs/20035/dcrcwe3.pdf) Series= CRCW..e3 | Res= 32.4 kOhm Power= 63.0 mW Tolerance= 1.0%
1 | $0.01
0402 3 mm²
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

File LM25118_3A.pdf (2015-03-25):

## WEBENCH ® Design Report


WEBENCH®
NOPB 8.0V-30.0V to 12.00V @ 3.0A March 25, 2015 08:01:00 GMT-07:00

Design

Copyright © 2015, Texas Instruments Incorporated | 2 | ti.com/webench
# Name | Manufacturer | Part Number | Properties | Qty Price | Footprint

9. Cvcc | MuRata | GRM155R61A105KE15D (http://search.murata.co.jp/Ceramy/PnsearchViewAction.do) Series= X5R | Cap= 1.0 uF VDC= 10.0 V IRMS= 0.0 A
1 | $0.01
| | | | | 0402 3 mm²
10. Cvccx | TDK | C1608X5R1C105K (http://www.tdk.co.jp/tefe02/e2442%5Fc.pdf) Series= X5R | Cap= 1.0 uF ESR= 5.713 mOhm VDC= 16.0 V IRMS= 0.0 A
1 | $0.01
| | | | | 0603 5 mm²
11. D1 | Diodes Inc. | PDS760-13 | VF@Io= 560.0 mV VRRM= 60.0 V
1 | $0.60

PowerDI5 50 mm²
12. D2 | Diodes Inc. | PDS760-13 | VF@Io= 560.0 mV VRRM= 60.0 V
1 | $0.60

PowerDI5 50 mm²
13. D3 | Diodes Inc. | PDS760-13 | VF@Io= 560.0 mV VRRM= 60.0 V
1 | $0.60

PowerDI5 50 mm²
14. D4 | Diodes Inc. | PDS760-13 | VF@Io= 560.0 mV VRRM= 60.0 V
1 | $0.60

PowerDI5 50 mm²
15. L1 | Bourns | SRP1270-100M (http://www.bourns.com/data/global/pdfs/SRP1270.pdf) | L= 10.0 µH DCR= 16.8 mOhm
1 | $0.60

SRP1270 246 mm²
16. M1 | Texas Instruments | CSD18504Q5A (http://www.ti.com/lit/ds/symlink/csd18504q5a.pdf) | VdsMax= 40.0 V IdsMax= 50.0 Amps
1 | $0.56

TRANS_NexFET_Q5A 55
mm²
17. M2 | Texas Instruments | CSD16340Q3 (http://www.ti.com/lit/ds/symlink/csd16340q3.pdf) | VdsMax= 25.0 V IdsMax= 60.0 Amps
1 | $0.44

TRANS_NexFET_Q3 19
mm²
18. Rcomp | Vishay-Dale | CRCW040230K9FKED (http://www.vishay.com/docs/20035/dcrcwe3.pdf) Series= CRCW..e3 | Res= 30.9 kOhm Power= 63.0 mW Tolerance= 1.0%
1 | $0.01
0402 3 mm²
19. Renable | Vishay-Dale | CRCW04021M00FKED (http://www.vishay.com/docs/20035/dcrcwe3.pdf) Series= CRCW..e3 | Res= 1000.0 kOhm Power= 63.0 mW Tolerance= 1.0%
1 | $0.01
0402 3 mm²
20. Rfbb | Vishay-Dale | CRCW04021K00FKED (http://www.vishay.com/docs/20035/dcrcwe3.pdf) Series= CRCW..e3 | Res= 1000.0 Ohm Power= 63.0 mW Tolerance= 1.0%
1 | $0.01
0402 3 mm²
21. Rfbt | Vishay-Dale | CRCW04028K66FKED (http://www.vishay.com/docs/20035/dcrcwe3.pdf) Series= CRCW..e3 | Res= 8.66 kOhm Power= 63.0 mW Tolerance= 1.0%
1 | $0.01
0402 3 mm²
22. Rsense | Susumu Co Ltd | PRL1632-R015-F-T1 (http://www.susumu.co.jp/english/pdf/products-j01-07.pdf) Series= 237 | Res= 15.0 mOhm Power= 1.0 W Tolerance= 1.0%
1 | $0.19
1206 11 mm²
23. Rt | Vishay-Dale | CRCW040218K7FKED (http://www.vishay.com/docs/20035/dcrcwe3.pdf) Series= CRCW..e3 | Res= 18.7 kOhm Power= 63.0 mW Tolerance= 1.0%
1 | $0.01
0402 3 mm²
24. Ruv1 | Vishay-Dale | CRCW040232K4FKED (http://www.vishay.com/docs/20035/dcrcwe3.pdf) Series= CRCW..e3 | Res= 32.4 kOhm Power= 63.0 mW Tolerance= 1.0%
1 | $0.01
0402 3 mm²
25. Ruv2 | Vishay-Dale | CRCW04027K50FKED (http://www.vishay.com/docs/20035/dcrcwe3.pdf) Series= CRCW..e3 | Res= 7.5 kOhm Power= 63.0 mW Tolerance= 1.0%
1 | $0.01
0402 3 mm²

Copyright © 2015, Texas Instruments Incorporated; ti.com/webench; # Name; Manufacturer; Part Number; Properties; Qty Price; Footprint; Texas Instruments; LM25118Q1MH/NOPB; Switcher; MXA20A 71 mm²; SW Ipk; 3.00 Output Current (A); SW Ipk(A); Vin= 19.0V Vin= 30.0V; D3 Tj(degC); Cout IRMS; Cout IRMS(A); Diode Pd; Diode Pd(W); Cin Pd; Cin Pd(W)

Vin= 8.0V Vin= 19.0V Vin= 30.0V

Copyright © 2015, Texas Instruments Incorporated; ti.com/webench; M1 ThetaJA; 3.00 Output Current (A); M1 ThetaJA(degC/ W); L Ipp; L Ipp(A); M2 PdSw(W); Cout Pd(W); M2 Irms(A)

Vin= 8.0V Vin= 19.0V Vin= 30.0V
M2 PdSw

Cout Pd

M2 Irms

Copyright © 2015, Texas Instruments Incorporated; ti.com/webench; Vin= 8.0V; 3.00 Output Current (A); Diode 2 Power Dissipation(OpvalUnits.PD); D1 Tj(degC); Iin Avg; Iin Avg(A); M1 TjOP(degC)

Diode 2 Power Dissipation

Vin= 8.0V Vin= 19.0V Vin= 30.0V

IC Tj(degC)

M1 TjOP

Copyright © 2015, Texas Instruments Incorporated; ti.com/webench; M1 PdCond; 3.00 Output Current (A); M1 PdCond(W); Duty Cycle; Duty Cycle(%); M2 PdCond(W); Vin= 8.0V; Diode 4 Power Dissipation(OpvalUnits.PD); Vin= 19.0V Vin= 30.0V; D4 Tj(degC)

Vin= 8.0V Vin= 19.0V Vin= 30.0V
M2 PdCond

Diode 4 Power Dissipation

Copyright © 2015, Texas Instruments Incorporated; ti.com/webench; Efficiency; 3.00 Output Current (A); Efficiency(%); M2 Rdson; Vin= 19.0V Vin= 30.0V; M2 Rdson(Ohm); M1 Rdson(Ohm); M2 ThetaJA; M2 ThetaJA(degC/ W); Pout; Pout(W)

Vin= 8.0V Vin= 19.0V Vin= 30.0V
M1 Rdson
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

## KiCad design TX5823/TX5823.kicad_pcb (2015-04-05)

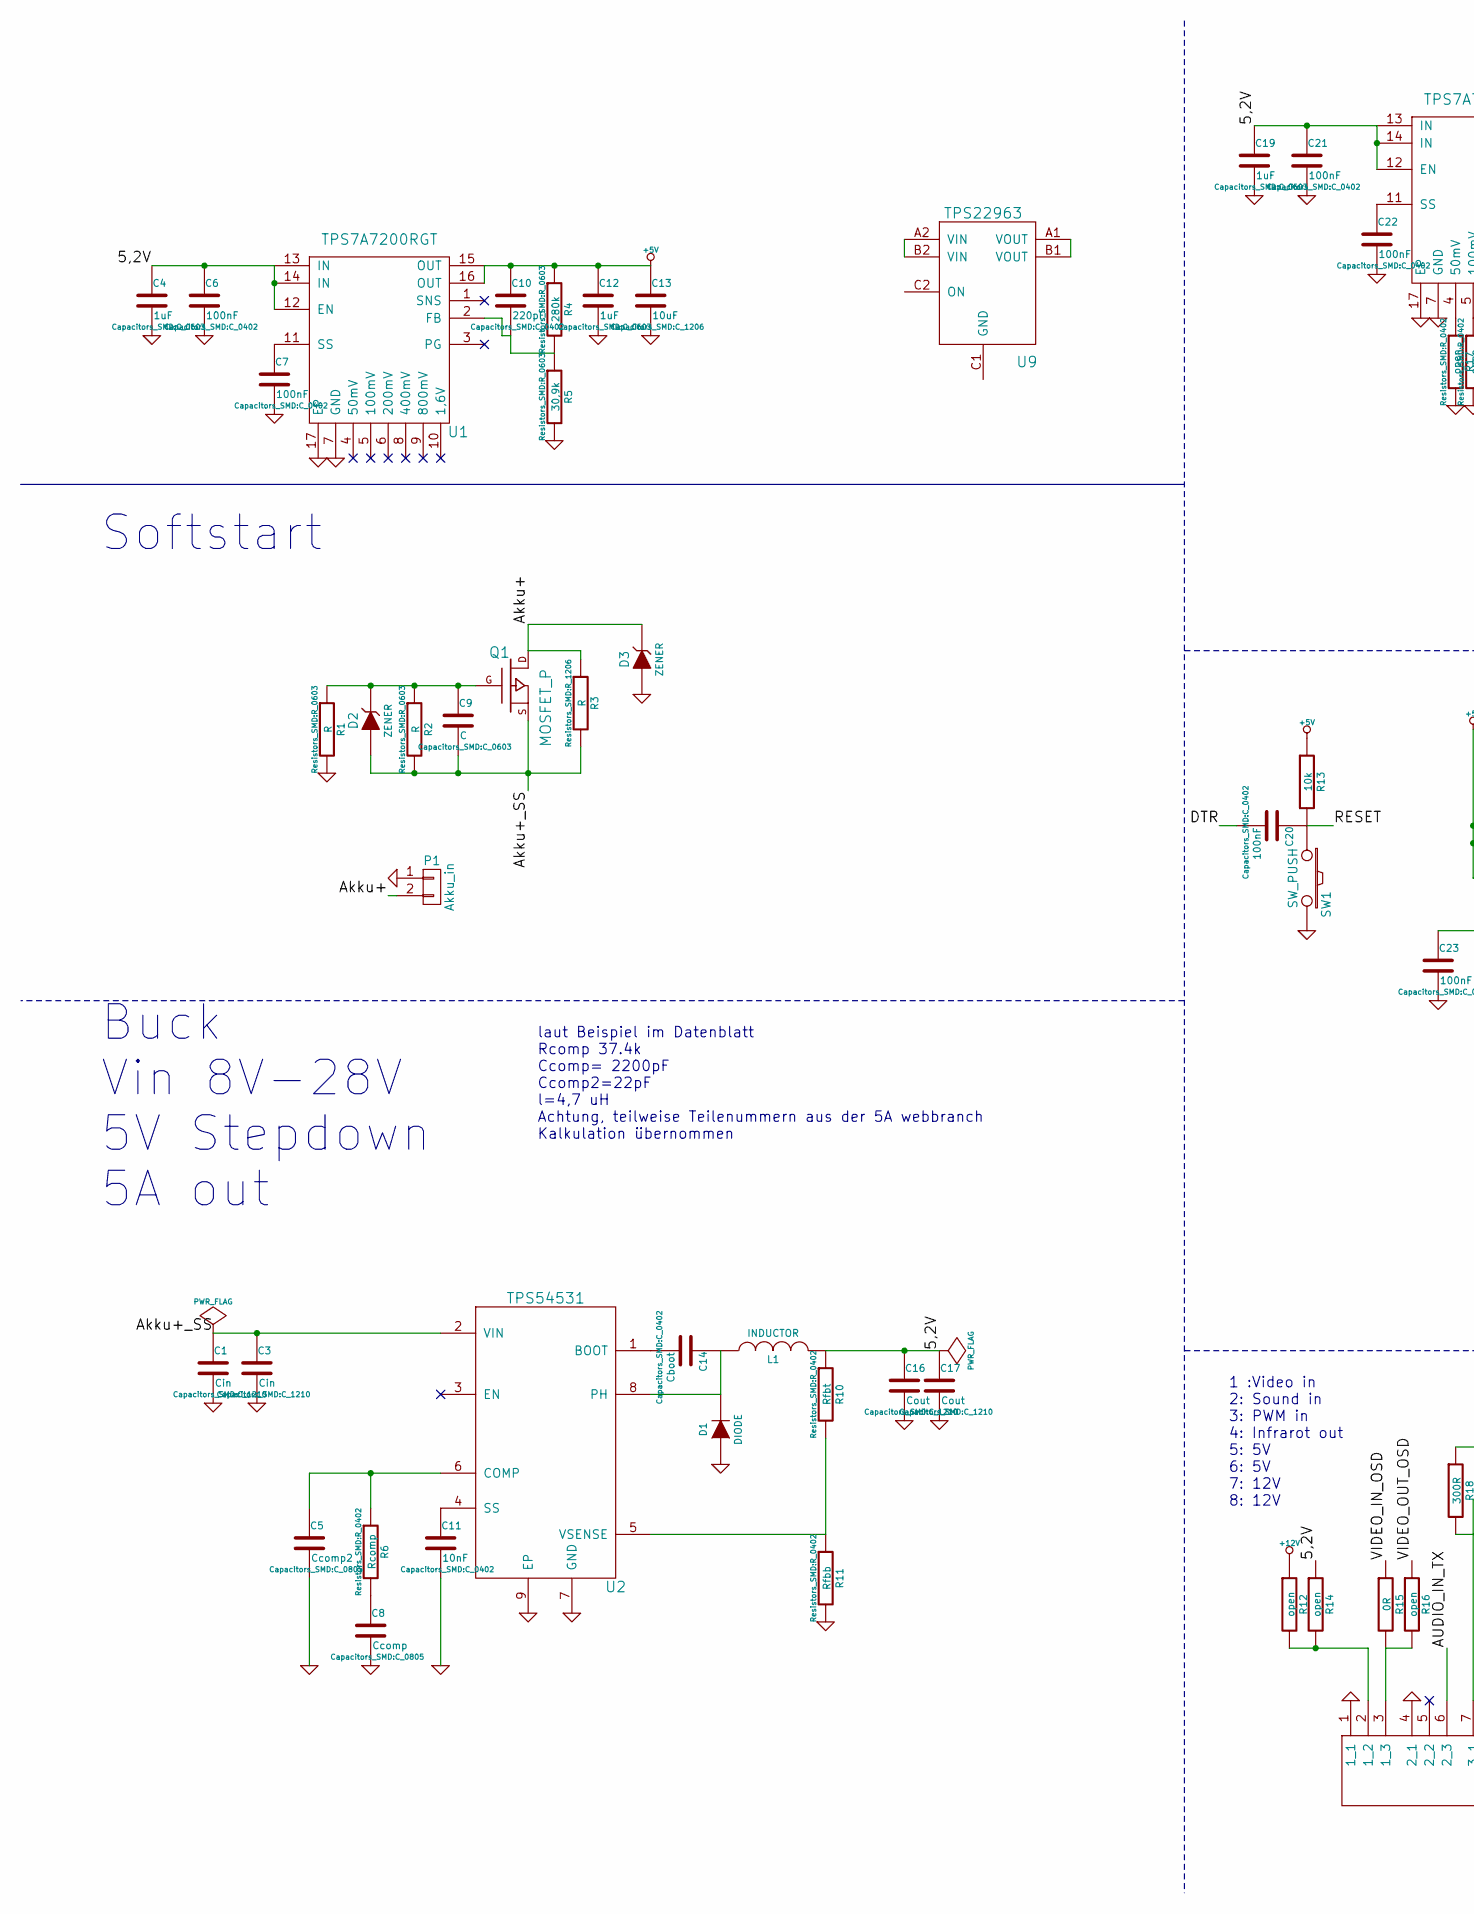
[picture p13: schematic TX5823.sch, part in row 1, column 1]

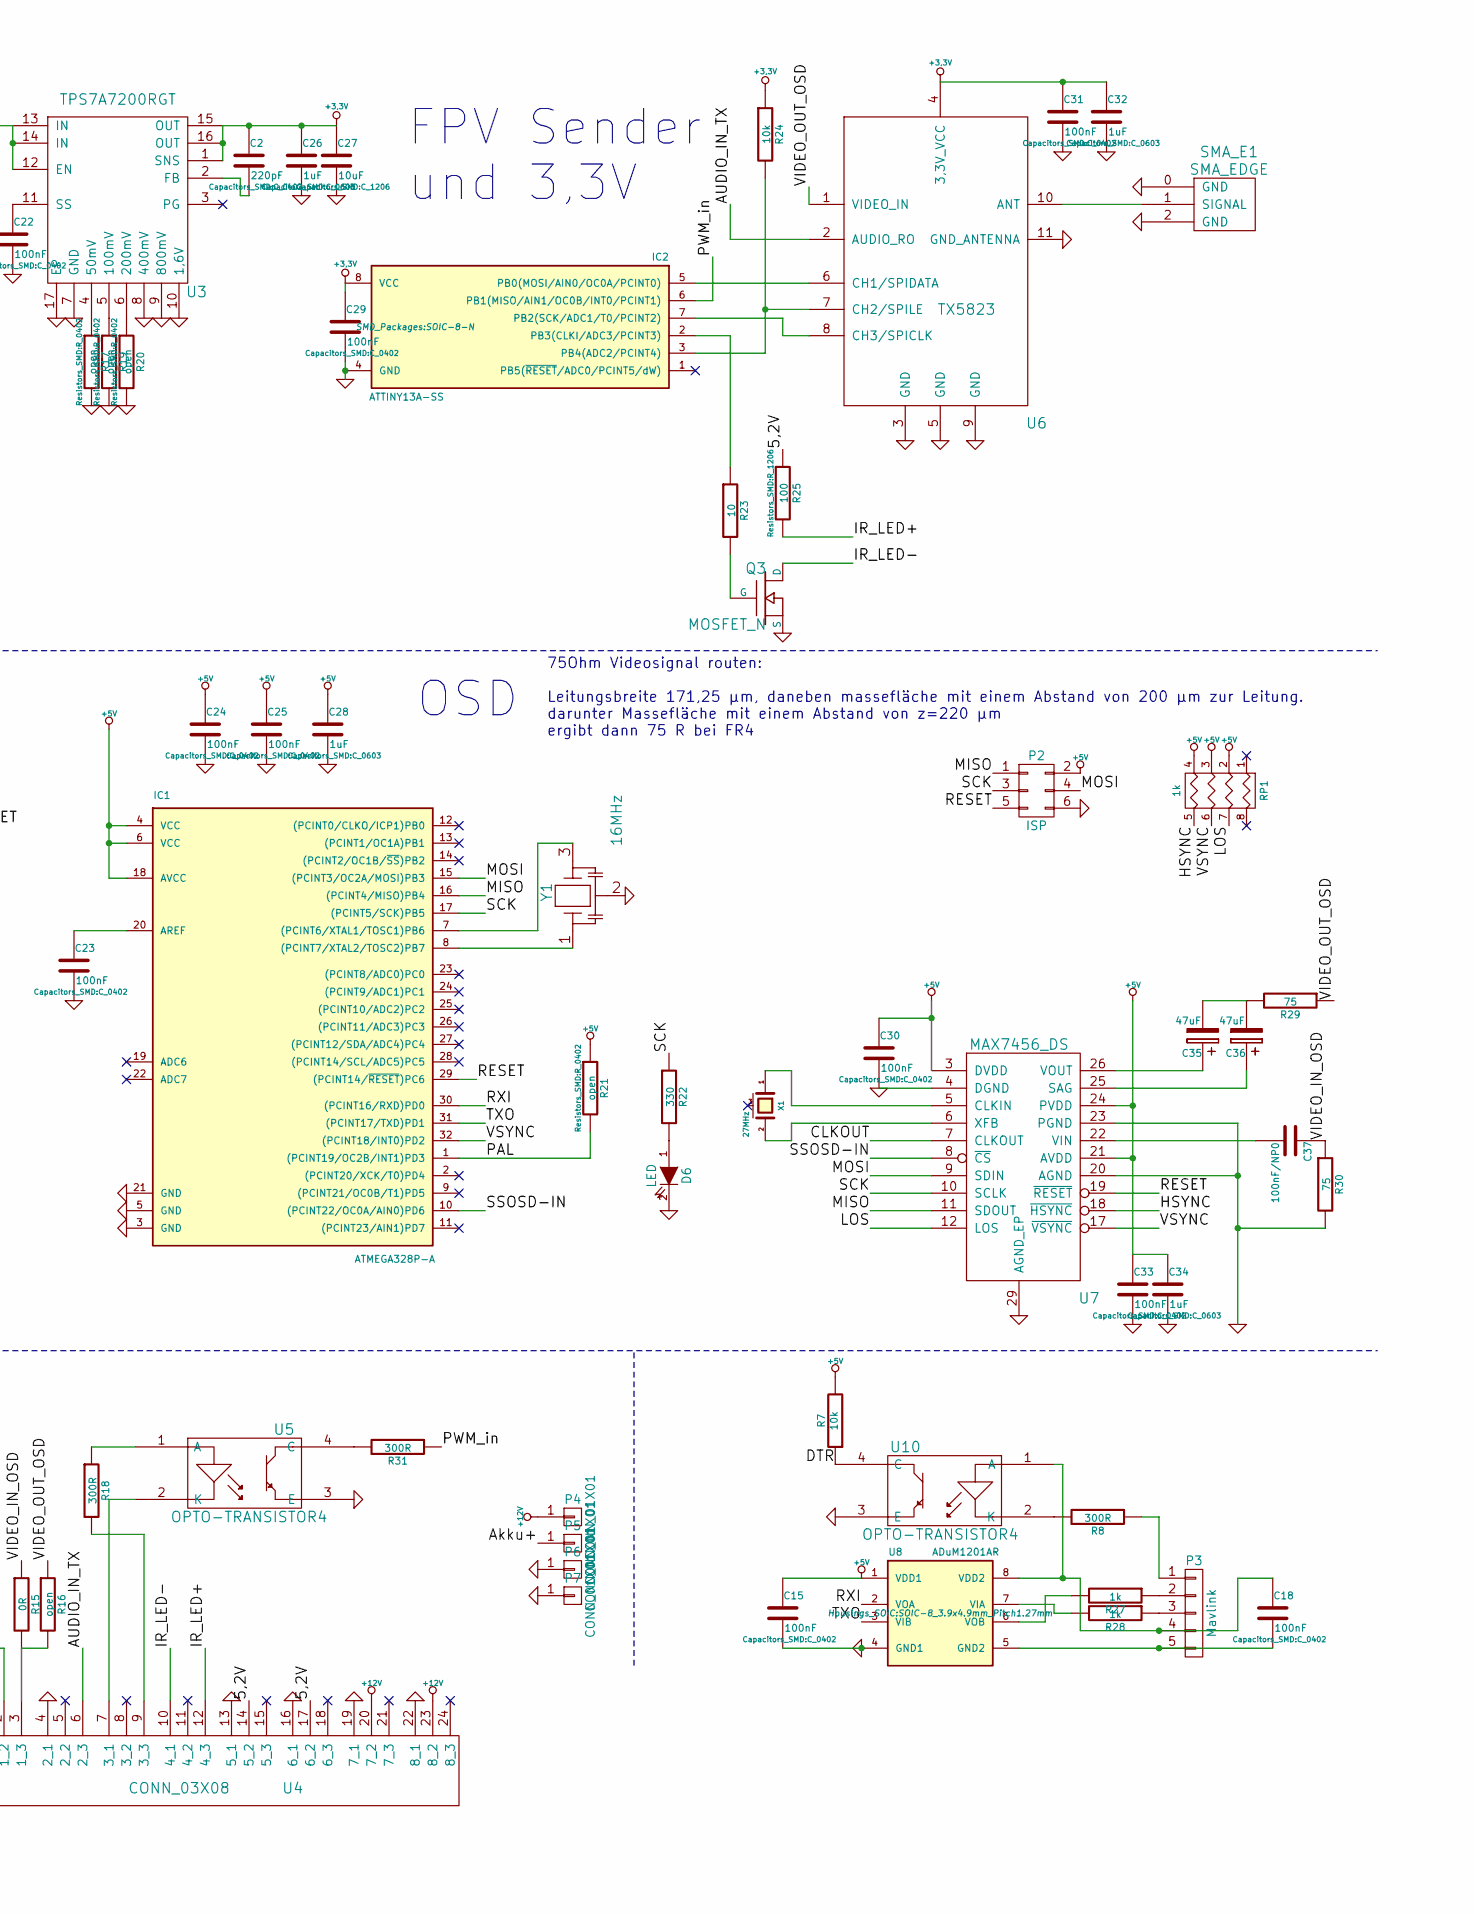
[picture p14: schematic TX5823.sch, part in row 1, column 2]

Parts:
C1, C3: Cin; C_1210
C2, C10: 220pF; C_0402
C4, C12, C19, C26, C28, C32, C34: 1uF; C_0603
C5: Ccomp2; C_0805
C6, C7, C15, C18, C20, C21, C22, C23, C24, C25, C29, C30, C31, C33: 100nF; C_0402
C8: Ccomp; C_0805
C9: C; C_0603
C11: 10nF; C_0402
C13, C27: 10uF; C_1206
C14: Cboot; C_0402
C16, C17: Cout; C_1210
C35, C36: 47uF; TantalC_SizeB_EIA-3528_Reflow
C37: 100nF/NP0; C_1206
D1: DIODE; POWERDI5
D2: ZENER; Diode-MiniMELF_Standard
D3: ZENER; Diode-SMB_Standard
D6: LED; LED-0603
IC1: ATMEGA328P-A; TQFP-32_7x7mm_Pitch0.8mm
IC2: ATTINY13A-SS; SOIC-8-N
L1: INDUCTOR; Choke_SMD_Wuerth-WE-PD-Typ-LS_Handsoldering
P1: Akku_in; Socket_Strip_Angled_1x02
P2: ISP; micro_match3x2
P3: Mavlink; Connector_Molex_PicoBlade_53261-0571
P4, P5, P6, P7: CONN_01X01; Pin_Header_Straight_1x01
Q1: MOSFET_P; SO8_WITH_EP
Q3: MOSFET_N; SOT23_GDS
R1, R2: R; R_0603
R3: R; R_1206
R4: 280k; R_0603
R5: 30,9k; R_0603
R6: Rcomp; R_0402
R7, R13, R24: 10k; R_0603
R8: 300R; R_0603
R10: Rfbt; R_0402
R11: Rfbb; R_0402
R12, R14, R16: open; R_0603
R15: 0R; R_0603
R17, R19, R20, R21: open; R_0402
R18: 300R; R_0805
R22: 330; R_0805
R23: 10; R_0805
R25: 100; R_1206
R27, R28: 1k; R_0603
R29, R30: 75; C_0805
R31: 300R; C_0805
RP1: 1k; R_Array_Concave_4x0603
SMA_E1: SMA_EDGE
SW1: SW_PUSH; EVQP7A
U1, U3: TPS7A7200RGT; QFN-16-1EP_3x3mm_Pitch0.5mm
U2: TPS54531; SO8_EP
U4: CONN_03X08; Conn_03x08
U5, U10: OPTO-TRANSISTOR4; SO-4
U6: TX5823
U7: MAX7456_DS; TSSOP-28_4.4x9.7mm_Pitch0.65mm_EP
U8: ADuM1201AR; SOIC-8_3.9x4.9mm_Pitch1.27mm
U9: TPS22963; DSBGS(6)
X1: 27MHz; CRYSTAL_MT
Y1: 16MHz; CerOsc_3,2x1,3

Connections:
+3.3V: C2.1, C26.1, C27.1, C29.1, C31.1, C32.1, IC2.8 (VCC), R24.1, U3.1 (SNS), U3.15 (OUT), U3.16 (OUT), U6.4 (3,3V_VCC)
+5V: C10.1, C12.1, C13.1, C15.1, C24.1, C25.1, C28.1, C30.1, C33.1, C34.1, IC1.4 (VCC), IC1.6 (VCC), IC1.18 (AVCC), P2.2, R4.1, R7.2, R13.1, R21.1, RP1.2, RP1.3, RP1.4, U1.15 (OUT), U1.16 (OUT), U7.3 (DVDD), U7.21 (AVDD), U7.24 (PVDD), U8.1 (VDD1)
+12V: P4.1, R12.1, U4.20 (7_2), U4.23 (8_2)
/5,2V: C4.1, C6.1, C16.1, C17.1, C19.1, C21.1, L1.2, R10.1, R14.1, R25.1, U1.12 (EN), U1.13 (IN), U1.14 (IN), U3.12 (EN), U3.13 (IN), U3.14 (IN), U4.14 (5_2), U4.17 (6_2)
/AUDIO_IN_TX: U4.6 (2_3), U6.2 (AUDIO_RO)
/Akku+: D3.2 (K), P1.2, P5.1, Q1.D, R3.1
/Akku+_SS: C1.1, C3.1, C9.2, D2.1 (A), Q1.S, R2.2, R3.2, U2.2 (VIN)
/CLKOUT: U7.7 (CLKOUT)
/DTR: C20.2, R7.1, U10.4 (C)
/HSYNC: RP1.5 (R4), U7.18 (~HSYNC)
/IR_LED+: R25.2, U4.12 (4_3)
/IR_LED-: Q3.D, U4.10 (4_1)
/LOS: RP1.7 (R2), U7.12 (LOS)
/MISO: IC1.16 ((PCINT4/MISO)PB4), P2.1, U7.11 (SDOUT)
/MOSI: IC1.15 ((PCINT3/OC2A/MOSI)PB3), P2.4, U7.9 (SDIN)
/PAL: IC1.1 ((PCINT19/OC2B/INT1)PD3), R21.2
/PWM_in: IC2.6 (PB1(MISO/AIN1/OC0B/INT0/PCINT1)), R31.1
/RESET: C20.1, IC1.29 ((PCINT14/~RESET~)PC6), P2.5, R13.2, SW1.1, U7.19 (~RESET)
/RXI: IC1.30 ((PCINT16/RXD)PD0), U8.2 (VOA)
/SCK: IC1.17 ((PCINT5/SCK)PB5), P2.3, R22.1, U7.10 (SCLK)
/SSOSD-IN: IC1.10 ((PCINT22/OC0A/AIN0)PD6), U7.8 (~CS)
/TXO: IC1.31 ((PCINT17/TXD)PD1), U8.3 (VIB)
/VIDEO_IN_OSD: C37.1, R15.1, R30.1
/VIDEO_OUT_OSD: R16.1, R29.1, U6.1 (VIDEO_IN)
/VSYNC: IC1.32 ((PCINT18/INT0)PD2), RP1.6 (R3), U7.17 (~VSYNC)
GND: C1.2, C3.2, C4.2, C5.2, C6.2, C7.2, C8.2, C11.2, C12.2, C13.2, C15.2, C16.2, C17.2, C19.2, C21.2, C22.2, C23.2, C24.2, C25.2, C26.2, C27.2, C28.2, C29.2, C30.2, C31.2, C32.2, C33.2, C34.2, D1.1 (A), D3.1 (A), D6.2 (K), IC1.3 (GND), IC1.5 (GND), IC1.21 (GND), IC2.4 (GND), P1.1, P2.6, P6.1, P7.1, Q3.S, R1.2, R5.2, R11.2, R17.2, R19.2, R20.2, R30.2, SMA_E1.0 (GND), SMA_E1.2 (GND), SW1.2, U1.7 (GND), U1.17 (EP), U2.7 (GND), U2.9 (EP), U3.7 (GND), U3.8 (400mV), U3.9 (800mV), U3.10 (1,6V), U3.17 (EP), U4.1 (1_1), U4.4 (2_1), U4.13 (5_1), U4.16 (6_1), U4.19 (7_1), U4.22 (8_1), U5.3 (E), U6.3 (GND), U6.5 (GND), U6.9 (GND), U6.11 (GND_ANTENNA), U7.4 (DGND), U7.20 (AGND), U7.23 (PGND), U7.29 (AGND_EP), U8.4 (GND1), U10.3 (E), Y1.2
unnamed: C2.2, U3.2 (FB)
unnamed: C5.1, R6.1, U2.6 (COMP)
unnamed: C7.1, U1.11 (SS)
unnamed: C8.1, R6.2
unnamed: C9.1, D2.2 (K), Q1.G, R1.1, R2.1
unnamed: C10.2, R4.2, R5.1, U1.2 (FB)
unnamed: C11.1, U2.4 (SS)
unnamed: C14.1, D1.2 (K), L1.1, U2.8 (PH)
unnamed: C14.2, U2.1 (BOOT)
unnamed: C18.1, P3.4, U8.8 (VDD2), U10.1 (A)
unnamed: C18.2, P3.5, U8.5 (GND2)
unnamed: C22.1, U3.11 (SS)
unnamed: C23.1, IC1.20 (AREF)
unnamed: C35.1, U7.26 (VOUT)
unnamed: C35.2, C36.2, R29.2
unnamed: C36.1, U7.25 (SAG)
unnamed: C37.2, U7.22 (VIN)
unnamed: D6.1 (A), R22.2
unnamed: IC1.7 ((PCINT6/XTAL1/TOSC1)PB6), Y1.3
unnamed: IC1.8 ((PCINT7/XTAL2/TOSC2)PB7), Y1.1
unnamed: IC2.2 (PB3(CLKI/ADC3/PCINT3)), R23.1
unnamed: IC2.3 (PB4(ADC2/PCINT4)), R24.2, U6.7 (CH2/SPILE)
unnamed: IC2.5 (PB0(MOSI/AIN0/OC0A/PCINT0)), U6.6 (CH1/SPIDATA)
unnamed: IC2.7 (PB2(SCK/ADC1/T0/PCINT2)), U6.8 (CH3/SPICLK)
unnamed: P3.1, R8.1
unnamed: P3.2, R27.1
unnamed: P3.3, R28.1
unnamed: Q3.G, R23.2
unnamed: R8.2, U10.2 (K)
unnamed: R10.2, R11.1, U2.5 (VSENSE)
unnamed: R12.2, R14.2, U4.2 (1_2)
unnamed: R15.2, R16.2, U4.3 (1_3)
unnamed: R17.1, U3.4 (50mV)
unnamed: R18.1, U5.1 (A)
unnamed: R18.2, U4.9 (3_3)
unnamed: R19.1, U3.5 (100mV)
unnamed: R20.1, U3.6 (200mV)
unnamed: R27.2, U8.6 (VOB)
unnamed: R28.2, U8.7 (VIA)
unnamed: R31.2, U5.4 (C)
unnamed: SMA_E1.1 (SIGNAL), U6.10 (ANT)
unnamed: U4.7 (3_1), U5.2 (K)
unnamed: U7.5 (CLKIN), X1.1
unnamed: U7.6 (XFB), X1.2
unnamed: U9.A1 (VOUT), U9.B1 (VOUT)
unnamed: U9.A2 (VIN), U9.B2 (VIN)

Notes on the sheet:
Buck Vin 8V-28V 5V Stepdown 5A out
FPV Sender und 3,3V
OSD
laut Beispiel im Datenblatt Rcomp 37.4k Ccomp= 2200pF Ccomp2=22pF l=4,7 uH Achtung, teilweise Teilenummern aus der 5A webbranch Kalkulation übernommen
1 :Video in 2: Sound in 3: PWM in 4: Infrarot out 5: 5V 6: 5V 7: 12V 8: 12V
75Ohm Videosignal routen: Leitungsbreite 171,25 µm, daneben massefläche mit einem Abstand von 200 µm zur Leitung. darunter Massefläche mit einem Abstand von z=220 µm ergibt dann 75 R bei FR4
Softstart

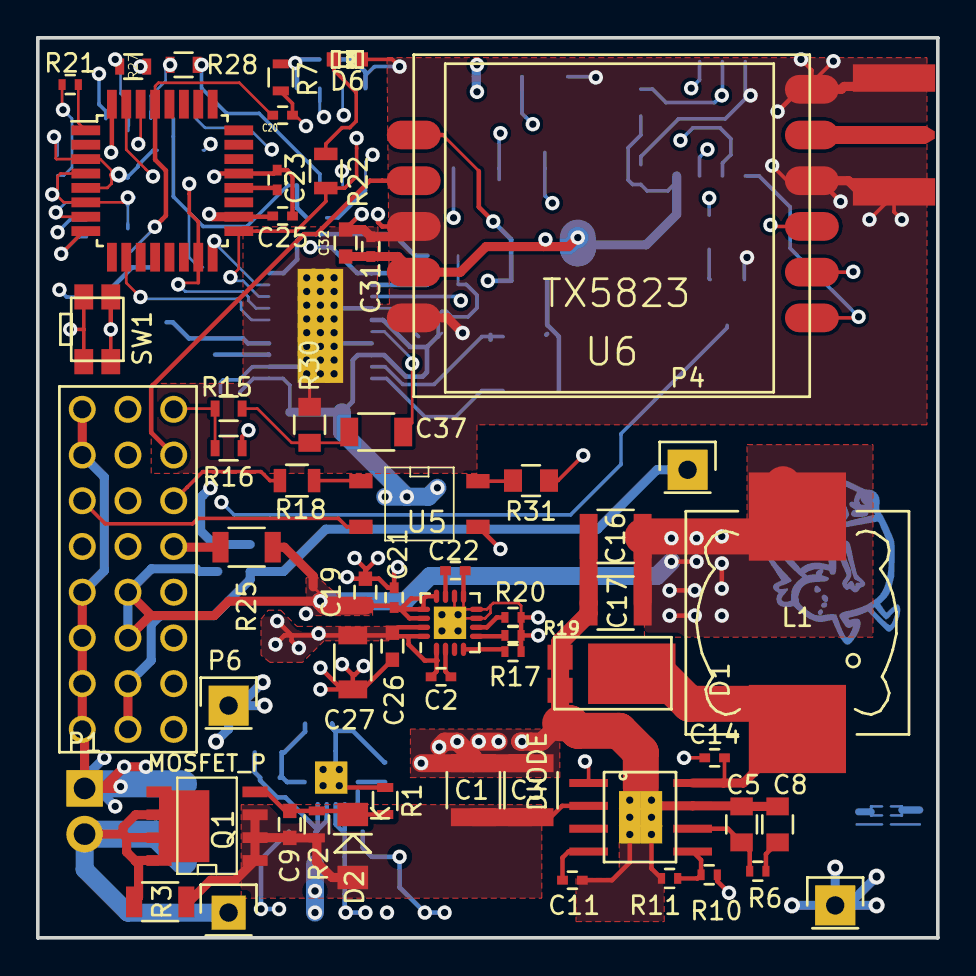
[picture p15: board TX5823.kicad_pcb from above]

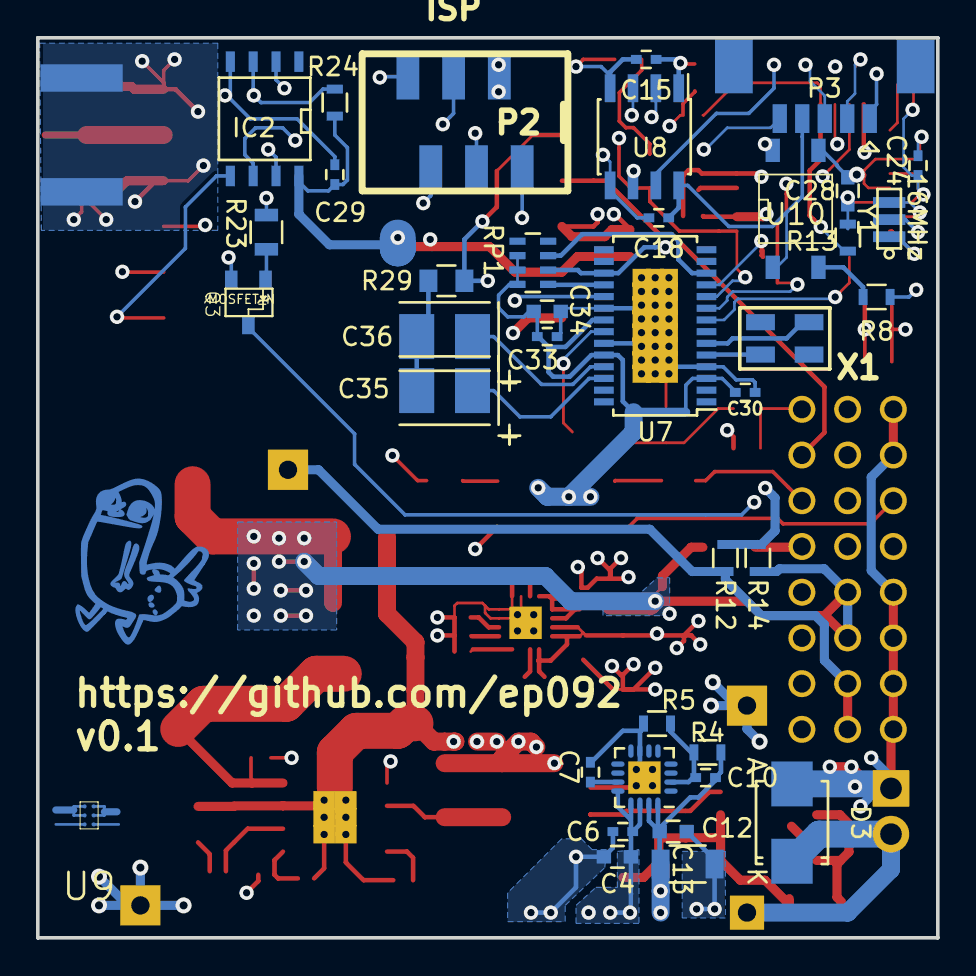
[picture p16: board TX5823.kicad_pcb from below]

Board: 4 copper layers, 50.0 x 50.0 mm, 97 parts (38 on the bottom side), 71 nets.

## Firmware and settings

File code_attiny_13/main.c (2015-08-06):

//hfuse FB
//lfuse 7A

#include <avr/interrupt.h>
#include <avr/io.h>
#include <util/delay.h>
#include <avr/pgmspace.h>


//user defined:
#define IR_LED_PORT PORTB
#define IR_LED_DDR DDRB
#define IR_LED_PIN PB3

#define PWM_IN_PORT PORTB
#define PWM_IN_DDR DDRB
#define PWM_IN_PIN PB1

#define SPI_DATA_PORT PORTB
#define SPI_DATA_DDR DDRB
#define SPI_DATA_PIN PB0

#define SPI_LE_PORT PORTB
#define SPI_LE_DDR DDRB
#define SPI_LE_PIN PB4

#define SPI_CLOCK_PORT PORTB
#define SPI_CLOCK_DDR DDRB
#define SPI_CLOCK_PIN PB2

#define TIME_BETWEEN_PHOTOS 3000

//settings for pwm signal
#define PWM_VALUE_0_MIN	105	//min length for the signal (pulse) to be detectet as "middle"
#define PWM_VALUE_0_MAX 135	//max length for the signal (pulse) to be detectet as "middle"
#define PWM_VALUE_MIN 75	//min length of the signal (pulse)
#define PWM_VALUE_MAX 175	//max length of the signal (pulse)


//non user defined:
#define IR_LED_ON 		IR_LED_PORT |= (1 << IR_LED_PIN)
#define IR_LED_OFF 		IR_LED_PORT &= ~(1 << IR_LED_PIN)
#define SPI_DATA_LOW 		SPI_DATA_PORT &= ~(1 << SPI_DATA_PIN)
#define SPI_DATA_HIGH 		SPI_DATA_PORT |= (1 << SPI_DATA_PIN)
#define SPI_LE_LOW 		SPI_LE_PORT &= ~(1 << SPI_LE_PIN)
#define SPI_LE_HIGH 		SPI_LE_PORT |= (1 << SPI_LE_PIN)
#define SPI_CLOCK_LOW 		SPI_CLOCK_PORT &= ~(1 << SPI_CLOCK_PIN)
#define SPI_CLOCK_HIGH 		SPI_CLOCK_PORT |= (1 <<SPI_CLOCK_PIN)

// Channels to sent to the SPI registers
const uint16_t channelTable[] PROGMEM = {
	// CH 1 CH 2 	CH 3 	CH 4 	CH 5 	CH 6 	CH 7 	CH 8
	0x7981, 0x758D, 0x7199, 0x6DA5, 0x69B1, 0x65BD, 0x6209, 0x5E15, // Band A
	0x5F9D, 0x6338, 0x6713, 0x6AAE, 0x6E89, 0x7224, 0x75BF, 0x799A, // Band B
	0x5A21, 0x562D, 0x5239, 0x4E85, 0x7D35, 0x8129, 0x851D, 0x8911, // Band E
	0x610C, 0x6500, 0x68B4, 0x6CA8, 0x709C, 0x7490, 0x7884, 0x7C38, // Band F / Airwave
	0x510A, 0x5827, 0x5F84, 0x66A1, 0x6DBE, 0x751B, 0x7C38, 0x8395  // Band R / Raceband
};

volatile uint8_t pwm_value = 0 ;
volatile uint8_t new_data = 0 ;

void canon_shutter_now(void){
	for(int i=0; i<16; i++) { 
		IR_LED_ON;
		_delay_us(15);
		IR_LED_OFF;
		_delay_us(15);
		
	} 
	_delay_us(7330); 
	for(int i=0; i<16; i++) { 
		IR_LED_ON;
		_delay_us(15);
		IR_LED_OFF;
		_delay_us(15);
		
	}
}

void canon_shutter_delayed(void){
	for(int i=0; i<16; i++) { 
		IR_LED_ON;
		_delay_us(11);
		IR_LED_OFF;
		_delay_us(11);
		
	} 
	_delay_us(5360); 
	for(int i=0; i<16; i++) { 
		IR_LED_ON;
		_delay_us(11);
		IR_LED_OFF;
		_delay_us(11);
		
	}
}


void serial_send_bit_1(void){
	SPI_CLOCK_LOW;
	_delay_us(1);
	SPI_DATA_HIGH;
	_delay_us(1);
	SPI_CLOCK_HIGH;
	_delay_us(1);
	SPI_CLOCK_LOW;
	_delay_us(1);
}

void serial_send_bit_0(void)
{
	SPI_CLOCK_LOW;
	_delay_us(1);
	SPI_DATA_LOW;
	_delay_us(1);
	SPI_CLOCK_HIGH;
	_delay_us(1);
	SPI_CLOCK_LOW;
	_delay_us(1);
}

void serial_enable_low(void){
	_delay_us(1);
	SPI_LE_LOW;
	_delay_us(1);
}

void serial_enable_high(void){
	_delay_us(1);
	SPI_LE_HIGH;
	_delay_us(1);
}

void set_channel(uint8_t channel){
	uint8_t i;
	uint16_t channelData;

	channelData = pgm_read_word_near(channelTable + channel);
	// 25 bits of data
	// Order: A0-3, !R/W, D0-D19
	// A0=1, A1=0, A2=0, A3=0, RW=1, D0-19=0 

	// 20 bytes of register data are sent, but the MSB 4 bits are zeros
	// register address = 0x1, write, data0-15=channelData data15-19=0x4

	serial_enable_high();
	_delay_us(1);
	serial_enable_low();
	
	// register 0x1
	serial_send_bit_1();
	serial_send_bit_0();
	serial_send_bit_0();
	serial_send_bit_0();

	// write to register
	serial_send_bit_1();

	// D0-D15
	for (i = 16; i > 0; i--){
	// check if bit is high or low
	if (channelData & 0x1){
		serial_send_bit_1();
	}
	else{
		serial_send_bit_0();
	}

	// Shift bits along to check the next one
	channelData >>= 1;
	}

	// Remaining D16-D19
	serial_send_bit_0();
	serial_send_bit_0();
	serial_send_bit_1();
	serial_send_bit_0();

	// Finished clocking data in
	serial_enable_high();
	_delay_us(1);
}

void int0_init(void){
	MCUCR |= (1<<ISC00);	//Any logical change on INT0 generates an interrupt request
	GIMSK |= (1<<INT0);	//External Interrupt Request 0 Enable
}

void timer_init(void){
	TCCR0B |= (1<<CS01) | (1<<CS00); //prescaler 64
}

void init (void){
	IR_LED_DDR |= (1<<IR_LED_PIN);
	PWM_IN_PORT |= (1<<PWM_IN_PIN);
	SPI_DATA_DDR |= (1<<SPI_DATA_PIN);
	SPI_LE_DDR |= (1<<SPI_LE_PIN);
	SPI_CLOCK_DDR |= (1<<SPI_CLOCK_PIN);
	serial_enable_high();
	SPI_CLOCK_LOW;	
}

int main(void) {
	uint8_t pwm_pulse_now;
	uint8_t pwm_pulse_last;
	uint8_t channel = 8;		//channel at startup
	init();
	timer_init();
	int0_init();
	set_channel(channel);
	sei();
	canon_shutter_now();
	_delay_ms(1000);
	pwm_value = 0;
	new_data = 0;
	_delay_ms(100);
	while (1){
		//wait for new data and detect timeout at pwm_in
		for(uint8_t i = 0; new_data==0 && i<200; i++){
			_delay_ms(1);
		}
		if (new_data) {
			pwm_pulse_last = pwm_pulse_now;
			pwm_pulse_now = pwm_value;
			if (pwm_pulse_now > PWM_VALUE_MIN && pwm_pulse_now < PWM_VALUE_0_MIN){		//switch channel
				if (pwm_pulse_last > PWM_VALUE_0_MIN && PWM_VALUE_0_MAX < 180){		//detect "falling edge"
					channel++;
					if (channel >=15){	//limit to A- and B-Band 
						channel = 0;
					}
					set_channel(channel);	
					_delay_ms(200); 
				}
			
			} else if(pwm_pulse_now > PWM_VALUE_0_MAX && pwm_pulse_now < PWM_VALUE_MAX){	//do photo
				while (pwm_value >PWM_VALUE_0_MAX && pwm_value < PWM_VALUE_MAX){	
					canon_shutter_now();
					_delay_ms(TIME_BETWEEN_PHOTOS);			//time between pictures
				}
			}
			
		}else{
			pwm_value = 0;
			pwm_pulse_last = 0;
			pwm_pulse_now = 0;
		}
		
		new_data = 0;
	}	
}

//saves the length of the pwm_pulse to pwm_value
ISR ( INT0_vect) {
	uint8_t counter = TCNT0; //buffer timervalue  
	TCNT0 = 0; //reset timer
	if (TIFR0 & (1<<TOV0)){	//timeroverflow
		TIFR0 = _BV(TOV0);
		if (PINB & (1<<PWM_IN_PIN)){
			pwm_value = 0;
			new_data = 1;
		}
	} else {

		pwm_value = counter;
		new_data = 1;
	}		
}

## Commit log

2015-03-27 Bauteile angelegt
    [TX5823.sch]
2015-03-27 an Schaltplan weitergearbeitet
    [TX5823.sch]
2015-03-28 an Schaltplan weitergearbeitet. 5V Buck
    [TX5823.sch]
2015-03-28 Teilenummern und connectoren hinzugefügt
    [TX5823.sch]
2015-03-28 an Steckern im Schaltplan weitergearbeitet
    [TX5823.sch]
2015-03-28 Schaltplan bereit für review
    [TX5823.sch]
2015-03-28 ERC errors weitestgehend korrigiert
    [TX5823.sch]
2015-03-29 an Schaltplan weitergearbeitet footprints hinzugefügt
    [TX5823.kicad_pcb, TX5823.sch]
2015-03-29 weitere Footprints zugeordnet grobe Anordnung der Bauteiele im Layout
    [TX5823.kicad_pcb, TX5823.sch]
2015-03-29 sma buchse hinzugefügt
    [TX5823.kicad_pcb, TX5823.sch]
2015-03-29 Bauteile grob angeordnet
    [TX5823.kicad_pcb, TX5823.sch]
2015-03-30 12V Wandler entfernt
    [TX5823.kicad_pcb, TX5823.sch]
2015-03-30 an Layout gearbeitet
    [TX5823.kicad_pcb, TX5823.sch]
2015-04-03 Layout fertig bis auf startup teil
    [TX5823.kicad_pcb, TX5823.sch]
2015-04-04 zusätzlicher LDO für OSD hinzugefügt Softstart hinzugefügt
    [TX5823.kicad_pcb, TX5823.sch]
2015-04-04 Verbindungspunkte für 12V BuckBoost Aufsteckplatine hinzugefügt
    [TX5823.kicad_pcb, TX5823.sch]
2015-04-04 Bestückungsdruck ausgerichtet
    [TX5823.kicad_pcb]
2015-04-04 DSBGA(&) Footprint für Löttests hinzugefügt. Keine relevanz für diese Platine
    [TX5823.kicad_pcb, TX5823.sch]
2015-04-04 Lötstop richtig eingestellt
    [TX5823.kicad_pcb]
2015-04-04 logo hinzugefügt
    [TX5823.kicad_pcb]
2015-04-04 Vias vom Rand weggerückt github link hinzugefügt
    [TX5823.kicad_pcb]
2015-04-04 letzte Änderungen für Fertigung Gerberdaten hinzugefügt
    [TX5823.kicad_pcb, TX5823.sch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]
2015-04-05 mavlink isolierung überarbeitet. adum hinzugefüt
    [TX5823.kicad_pcb, TX5823.sch]
2015-04-05 footprint adum angepasst
    [TX5823.sch]
2015-04-05 mavlink und adum geroutet
    [TX5823.kicad_pcb, TX5823.sch]
2015-04-05 5V Anbindung Atmel verbessert Bestückungsdruck hinzugefügt
    [TX5823.kicad_pcb]
2015-04-05 Neue Fertigungsdateien hinzugefügt
    [TX5823.kicad_pcb, TX5823.sch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]
2015-05-18 fertigungsdaten, gerberfiles und attiny13a programm hinzugefügt
    [TX5823.csv, TX5823.sch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]
2015-05-18 fehlerhafte gerberdateien gelöscht Readme aktualisiert
    [TX.GBL, TX.GBO, TX.GBS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]
2015-05-26 fotoauslösung und kanalwechsel über pwm hinzugefügt - ungetestet
2015-05-30 Timing für Kameraauslösung angepasst. Kameraauslösung und Kanalwahl getestet.

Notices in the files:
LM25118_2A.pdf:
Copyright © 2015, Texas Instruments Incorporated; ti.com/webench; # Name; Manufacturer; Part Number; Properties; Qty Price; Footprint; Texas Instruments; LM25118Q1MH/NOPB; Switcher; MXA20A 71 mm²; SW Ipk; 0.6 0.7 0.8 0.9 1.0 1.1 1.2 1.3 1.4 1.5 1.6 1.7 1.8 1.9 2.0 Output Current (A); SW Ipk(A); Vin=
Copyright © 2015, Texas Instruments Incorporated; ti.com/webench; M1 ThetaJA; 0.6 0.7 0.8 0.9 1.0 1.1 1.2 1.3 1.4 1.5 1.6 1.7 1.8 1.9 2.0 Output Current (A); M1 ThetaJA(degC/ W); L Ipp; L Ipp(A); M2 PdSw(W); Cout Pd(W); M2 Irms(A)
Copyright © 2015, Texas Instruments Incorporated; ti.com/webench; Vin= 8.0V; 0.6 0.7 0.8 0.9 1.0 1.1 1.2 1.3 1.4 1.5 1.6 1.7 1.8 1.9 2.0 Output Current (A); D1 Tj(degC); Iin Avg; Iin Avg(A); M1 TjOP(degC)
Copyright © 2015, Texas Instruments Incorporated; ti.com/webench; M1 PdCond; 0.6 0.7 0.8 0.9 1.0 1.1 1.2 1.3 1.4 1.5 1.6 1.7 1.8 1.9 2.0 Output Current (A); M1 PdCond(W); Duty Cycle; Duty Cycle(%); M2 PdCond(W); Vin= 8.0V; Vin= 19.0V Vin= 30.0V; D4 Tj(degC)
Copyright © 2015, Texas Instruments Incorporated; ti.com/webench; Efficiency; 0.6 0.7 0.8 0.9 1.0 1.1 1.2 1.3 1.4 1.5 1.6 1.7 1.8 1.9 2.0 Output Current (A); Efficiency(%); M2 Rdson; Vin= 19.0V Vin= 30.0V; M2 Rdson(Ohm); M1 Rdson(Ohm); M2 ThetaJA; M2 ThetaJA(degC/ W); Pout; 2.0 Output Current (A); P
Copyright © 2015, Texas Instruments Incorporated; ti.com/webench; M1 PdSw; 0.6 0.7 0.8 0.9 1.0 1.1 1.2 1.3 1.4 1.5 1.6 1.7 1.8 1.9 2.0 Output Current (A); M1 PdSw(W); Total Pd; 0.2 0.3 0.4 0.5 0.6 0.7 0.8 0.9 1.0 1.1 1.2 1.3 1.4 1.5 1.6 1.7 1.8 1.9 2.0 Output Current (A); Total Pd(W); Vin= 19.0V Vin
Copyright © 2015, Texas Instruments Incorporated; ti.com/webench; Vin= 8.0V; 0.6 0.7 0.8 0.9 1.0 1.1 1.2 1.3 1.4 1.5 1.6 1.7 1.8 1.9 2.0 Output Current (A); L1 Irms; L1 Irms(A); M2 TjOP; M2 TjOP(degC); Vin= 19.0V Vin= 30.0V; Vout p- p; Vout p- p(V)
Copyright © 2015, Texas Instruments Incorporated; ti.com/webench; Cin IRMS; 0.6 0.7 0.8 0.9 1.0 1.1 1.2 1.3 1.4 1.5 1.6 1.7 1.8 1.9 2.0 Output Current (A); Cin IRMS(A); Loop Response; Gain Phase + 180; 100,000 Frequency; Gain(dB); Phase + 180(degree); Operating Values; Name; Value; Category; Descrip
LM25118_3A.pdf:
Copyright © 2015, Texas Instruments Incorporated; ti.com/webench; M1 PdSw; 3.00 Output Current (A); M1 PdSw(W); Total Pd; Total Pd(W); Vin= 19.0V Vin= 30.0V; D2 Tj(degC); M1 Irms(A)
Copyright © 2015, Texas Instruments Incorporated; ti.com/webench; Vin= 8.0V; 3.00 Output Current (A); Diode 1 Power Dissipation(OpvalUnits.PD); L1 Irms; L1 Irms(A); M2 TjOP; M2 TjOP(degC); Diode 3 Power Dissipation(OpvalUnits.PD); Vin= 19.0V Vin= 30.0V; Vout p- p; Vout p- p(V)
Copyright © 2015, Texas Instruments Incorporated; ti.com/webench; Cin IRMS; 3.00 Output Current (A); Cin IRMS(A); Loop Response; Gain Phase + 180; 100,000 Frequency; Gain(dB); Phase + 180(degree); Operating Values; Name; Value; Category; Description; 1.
